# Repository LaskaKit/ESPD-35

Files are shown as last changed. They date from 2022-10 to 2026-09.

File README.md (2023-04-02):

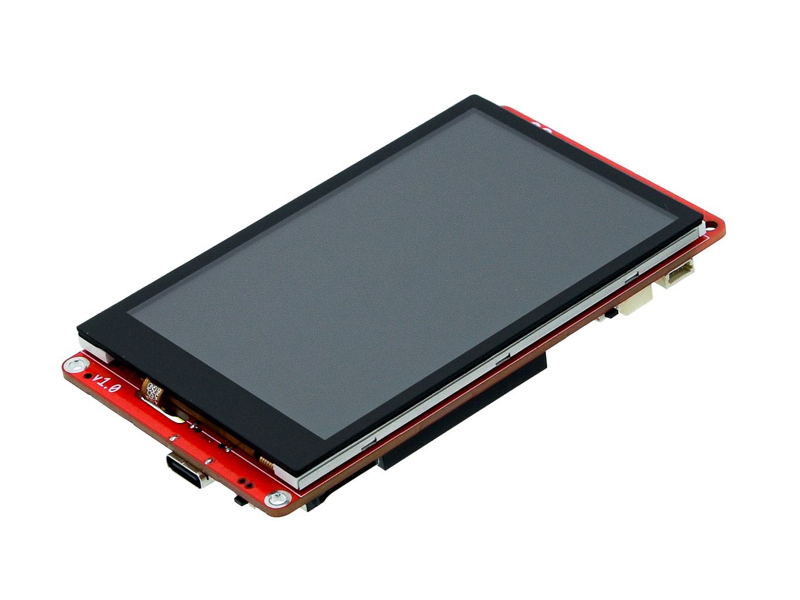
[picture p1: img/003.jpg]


# ESPD 3.5" - Development board with ESP32 and great TFT display

Don't you need a low-power board, but appreciate an active TFT display with a great viewing angle and quick connection of additional sensors and modules? What about ESPD-3.5"? Although it is a development kit, it is also suitable for fitting into the final product. The board has 4 mounting holes.

The 3.5" display has a resolution of 480x320 px and the number of colors of individual pixels can be up to 65535, and it also has a touch and includes a microSD card slot where you can store a lot of pictures and icons - instructions on how to do [this can be found here](https://blog.laskakit.cz/jak-nahrat-fotku-ikonu-do-esp32-a-zobrazit-na-tft-displeji/).

In addition to the SD card slot, the board has a module with ESP32 supporting Wi-Fi and Bluetooth connectivity, a built-in programmer with CH9102, a charging circuit for a battery with a charging current of 400mA, 2x uŠup connector for connecting sensors (for example [SHT40 ](https://www.laskakit.cz/laskakit-sht40-senzor-teploty-a-vlhkosti-vzduchu/)- temperature/humidity, [SCD41 ](https://www.laskakit.cz/laskakit-scd41-senzor-co2--teploty-a-vlhkosti-vzduchu/)- CO2/temperature/humidity or [BME280](https://www.laskakit.cz/arduino-senzor-tlaku--teploty-a-vlhkosti-bme280/) - pressure/temperature/humidity).

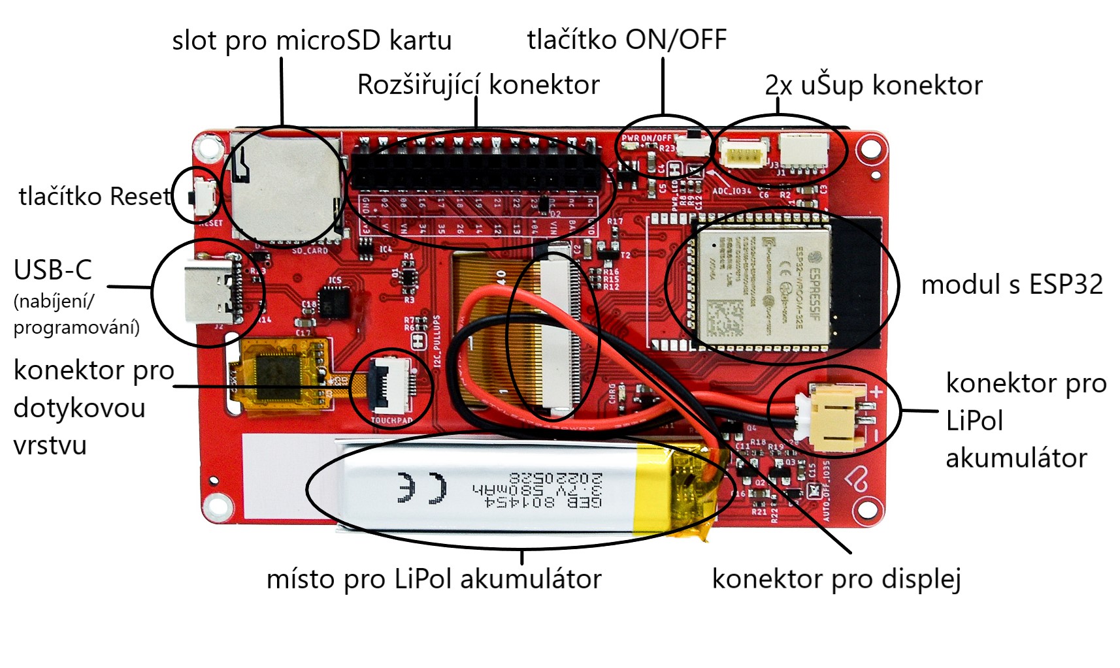
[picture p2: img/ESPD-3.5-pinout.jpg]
ESPD-3.5 pinout


The ESPD3.5" contains two buttons - RESET and Power ON/OFF - the button that turns the ESPD3.5" off (long press) and on (short press). The button is connected to GPIO35. You might also appreciate the 2x13 pin cavity rail where we connected the remaining ESP32 GPIO.

The USB-C connector is used for both programming and charging the Lipolka. We also left a [place on the board for a 580mAh Lipol battery](https://www.laskakit.cz/geb-lipol-baterie-801454-580mah-3-7v-jst-ph-2-0/) - so it won't get in the way anywhere else.

To measure the battery voltage, we also fitted a voltage divider connected to the battery and GPIO34 - don't forget to power the solder bridge.

**You can buy ESPD35 on https://www.laskakit.cz/laskakit-espd-35-esp32-3-5-tft-ili9488-touch/**

We have prepared some sample codes: https://github.com/LaskaKit/ESPD-35/tree/main/SW 

And also a box to print on a 3D printer: https://github.com/LaskaKit/ESPD-35/tree/main/3D

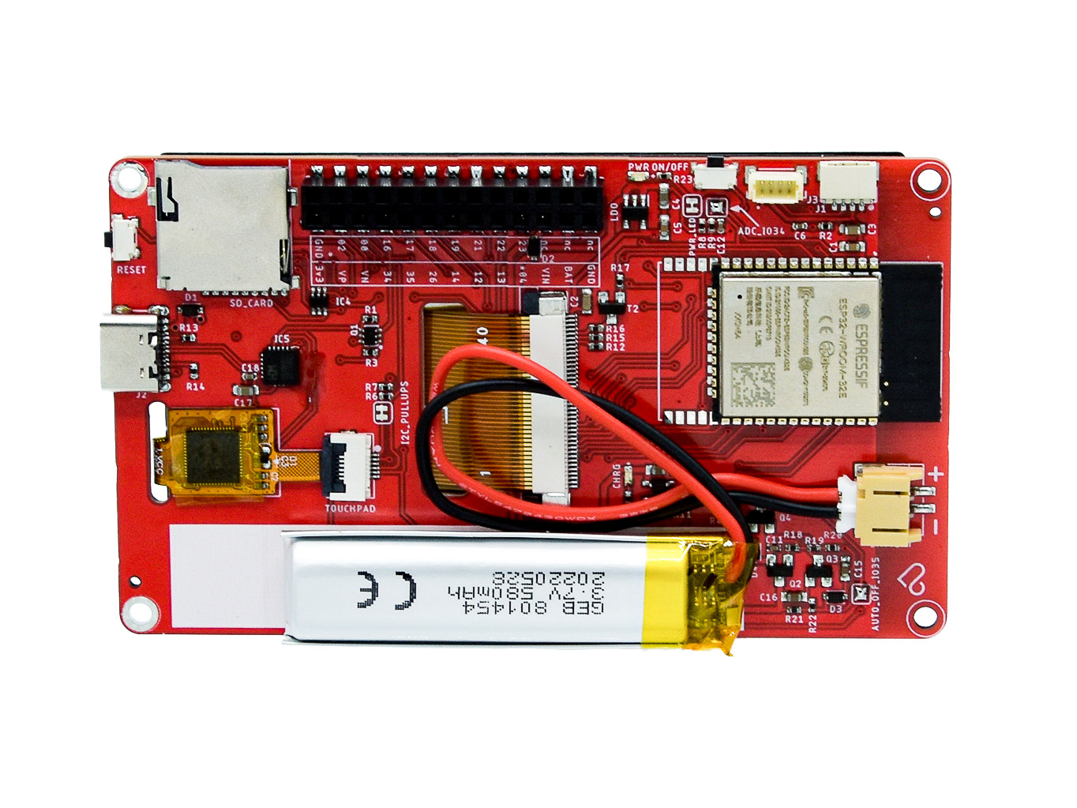
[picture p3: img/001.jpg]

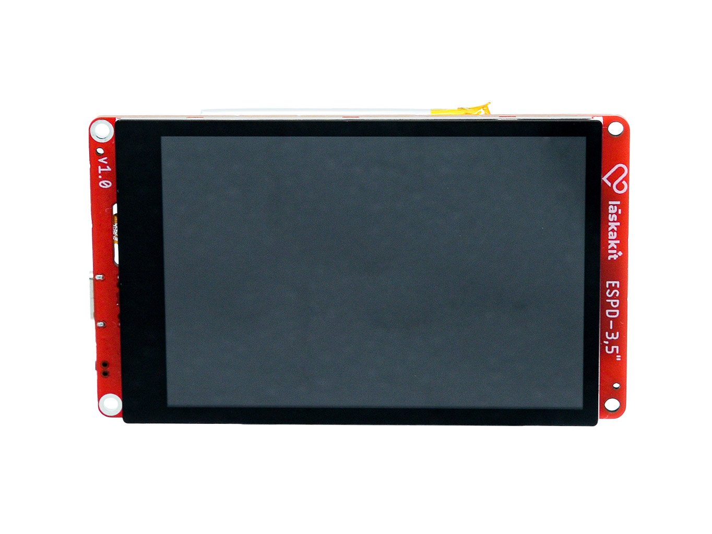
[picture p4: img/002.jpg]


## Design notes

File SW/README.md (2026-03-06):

# How to make display work

1. Download [CH343SER.EXE](http://www.wch-ic.com/search?t=all&q=CH9102) and install it.

2. Connect display to your PC and turn it on with button on the side of the device (**single press to turn on, long press to turn off**).

3. Open Device Manager (Start → Control Panel → Hardware and Sound → Device Manager) and find COM port number.

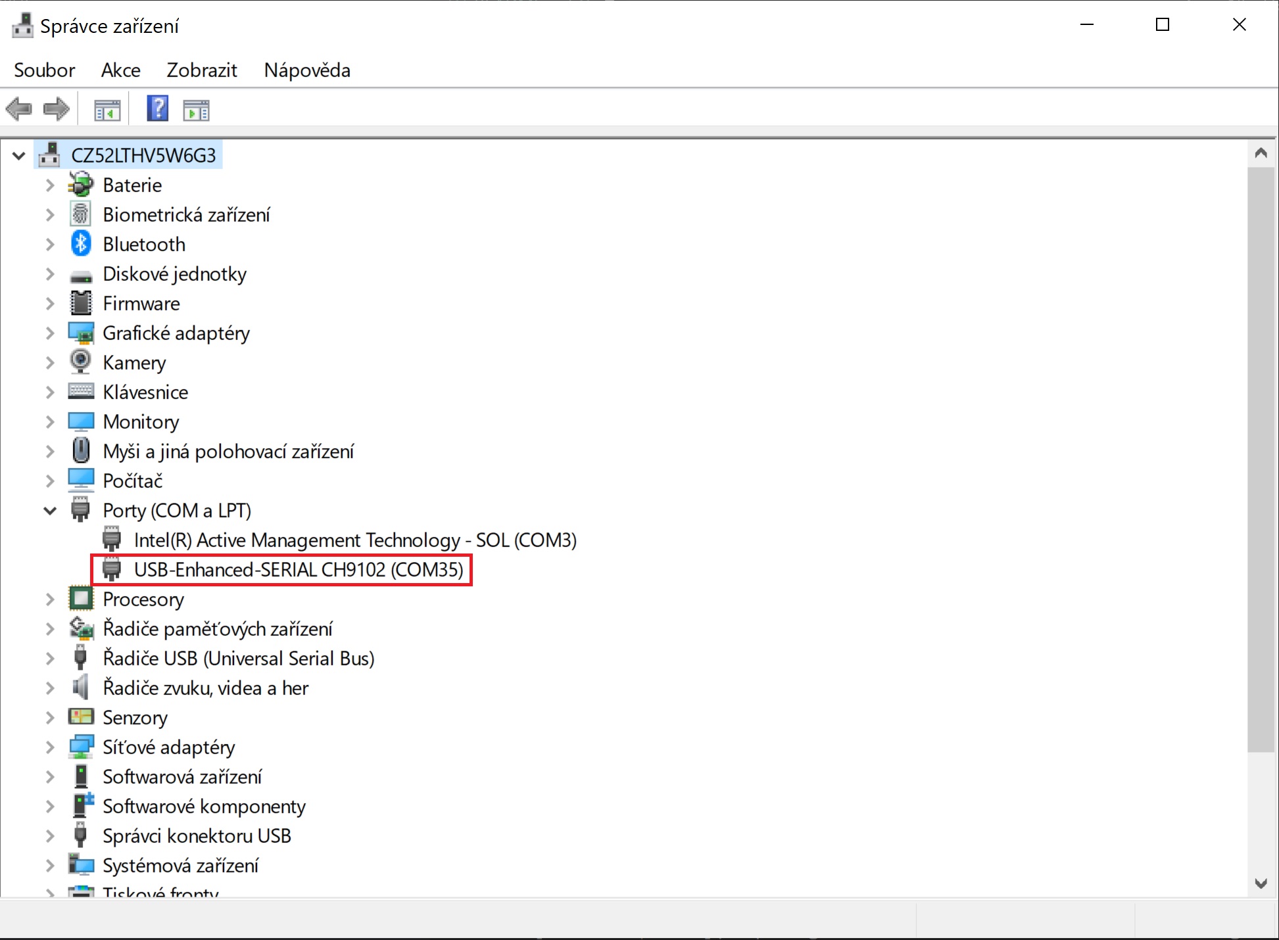
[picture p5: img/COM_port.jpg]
COM_port
    

## Arduino IDE
1. Download Github repository and look for project you want to try in [SW](../SW) folder.
2. Open example with Arduino IDE and set appropriate COM port and board type.
   
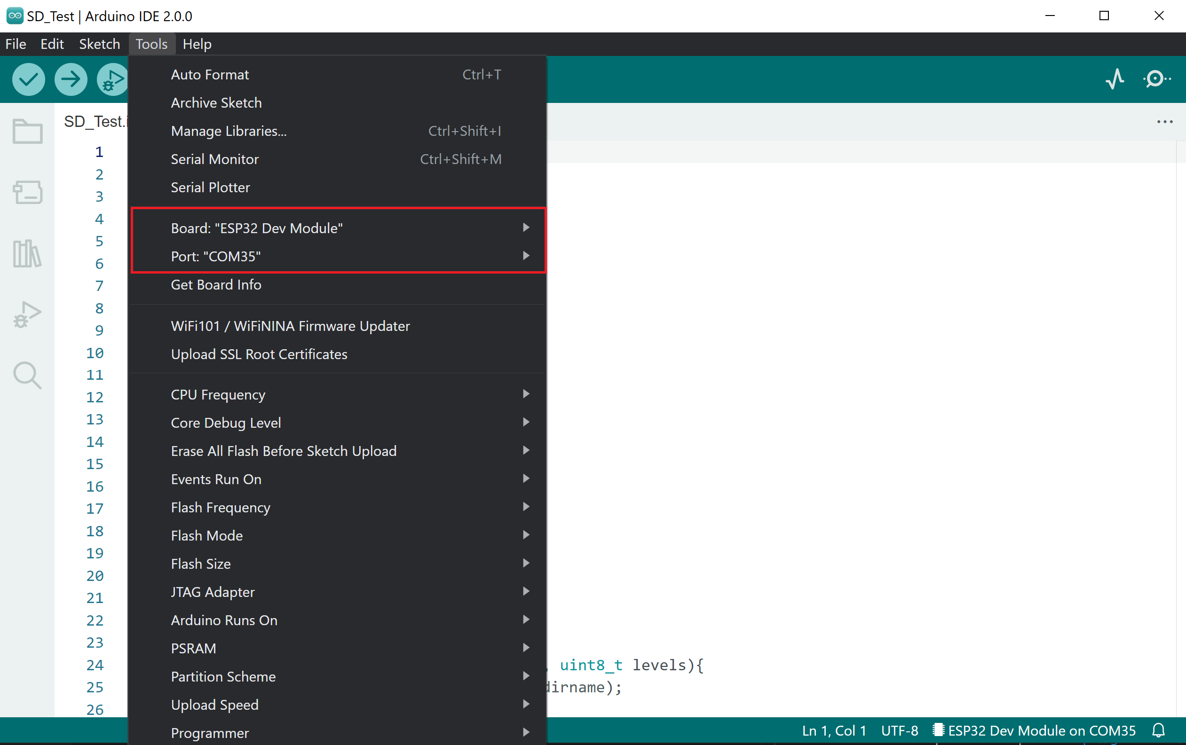
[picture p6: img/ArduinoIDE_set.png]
ArduinoIDE_set
    

3. Download necessary libraries.
4. You always need to adjust TFT_eSPI library to specific display. We  already prepared configuration file for this display ([Setup300_ILI9488_ESPD-3_5_v2.h](Setup300_ILI9488_ESPD-3_5_v2.h)) or for version v3 and above ([Setup300_ILI9488_ESPD-3_5_v3.h](https://github.com/LaskaKit/ESPD-35/blob/main/SW/Setup303_ILI9488_ESPD-3_5_v3.h)).
To use it, you need to copy this file to folder with your libraries: Arduino\libraries\TFT_eSPI\User_Setups.
1. In file Arduino\libraries\TFT_eSPI\User_Setup_Select.h you need to add this line: `#include <User_Setups/Setup300_ILI9488_ESPD-3_5_v2.h>` or for version v3 and above `#include <User_Setups/Setup300_ILI9488_ESPD-3_5_v3.h>`. into this section: `#ifndef USER_SETUP_LOADED` and comment `#include <User_Setup.h>` as shown in the picture and save it.
   
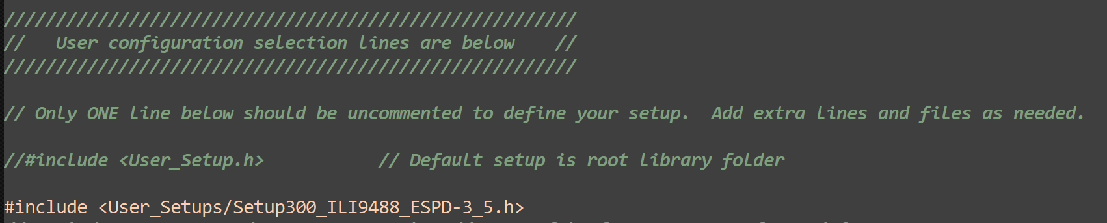
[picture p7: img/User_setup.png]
User_setup
   

2. Define version of hardware in code, for examples with touch functionality.
3. Upload the code.
## Platform IO
1. Download Github repository and look for project you want to try in [SW](https://github.com/LaskaKit/ESPD-35/tree/main/SW) folder.
2. Open example with Platform IO. COM port should be set automaticaly.
3. Libraries will be downloaded automatically, because of lib_deps in platformio.ini.
4. You always need to adjust TFT_eSPI library to specific display. For Platform IO, we can use build flags, so no file editing is necessary. Everything is already set in platformio.ini of every example.
    <p align="center">
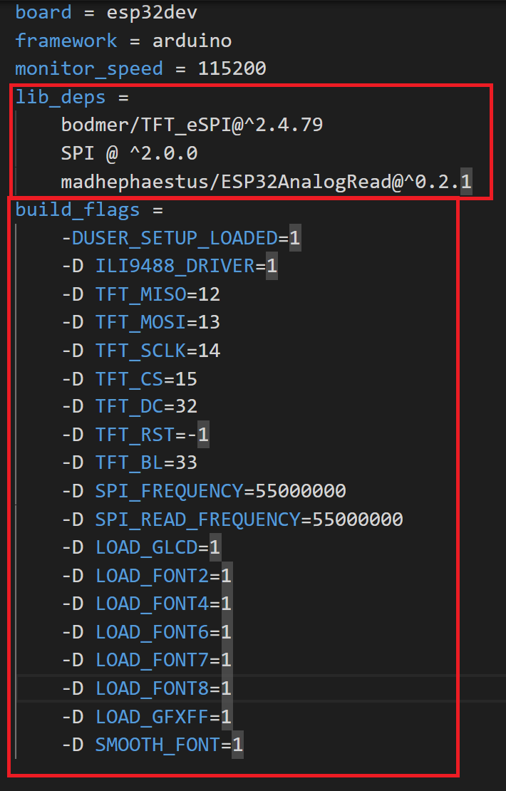
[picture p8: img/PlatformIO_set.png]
    
    </p>
5. Define version of hardware in code, for examples with touch functionality.
6. Upload the code.

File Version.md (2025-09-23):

### Version 3.2
- uSup connectors moved outside by 100 mil
- Switch moved far from connectors
- SHT40 moved.
#### Version 3.1
- Power button replaced with switch
#### Version 3.0
- New µc ESP32-S3-N16R8
- IPS Display
- New side GPIO connector
- added Temperature and Humidity SHT40 sensor
- (optional) added Inertial Measurement Unit BMI270
- (optional) I2S DAC and amplifier MAX98357A
#### Version 2.3
- Auto ON jumper added
#### Version 2.0
- SD card change to VSPI | Změna SD karty na VSPI
- HSPI only for display | HSPI pouze pro displej
- Změna pinu AUTO_OFF na GPIO17
#### Version 1.0
- Initial | Počáteční

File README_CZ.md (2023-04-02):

ESPD-3.5

# ESPD 3.5" - Vývojová deska s ESP32 a skvělým TFT displejem

Nepotřebuješ low-power desku, ale oceníš aktivní TFT displej se skvělým pozorovaním úhlem a rychlým připojením dalších čidel a modulů? ESPD-3.5". 
I když je to vývojový kit, je zároveň vhodný pro osazení do finálního produktu. Deska má 4 montážní díry. 

3.5" displej má rozlišení 480x320 px a počet barev jednotlivých pixelů může být až 65535 a navíc má i dotekovou 
ESPD-3.5" obsahuje slot na microSD kartu, kam si můžeš uložit spoustu obrázků a ikon - návod jak na to [najdeš tady](https://blog.laskakit.cz/jak-nahrat-fotku-ikonu-do-esp32-a-zobrazit-na-tft-displeji/).

Kromě slotu na SD kartu má deska samozřejmě modul s ESP32 podporující Wi-Fi i Bluetooth konektivitu, vestavěný programátor s CH9102, nabíjecí obvod pro akumulátor s nabíjecím
proudem 400mA, 2x konektor uŠup pro připojení čidel (například [SHT40](https://www.laskakit.cz/laskakit-sht40-senzor-teploty-a-vlhkosti-vzduchu/) - teplota/vlhkost, 
[SCD41](https://www.laskakit.cz/laskakit-scd41-senzor-co2--teploty-a-vlhkosti-vzduchu/) - CO2/teplota/vlhkost nebo [BME280](https://www.laskakit.cz/arduino-senzor-tlaku--teploty-a-vlhkosti-bme280/) - tlak/teplota/vlhkost).

ESPD-3.5 pinout

ESPD3.5" obsahuje dvě tlačítka - RESET a Power ON/OFF - tlačítko, kterým ESPD3.5" vypneš (dlouhý stisk) a zapneš (krátký stisk). Tlačítko je připojeno k GPIO35.
Ocenit bys mohl i dutinkovou lištu 2x13 pinů, kam jsme připojili zbylé GPIO ESP32.

USB-C konektor slouží jak k programování, tak i nabíjení Lipolky. 
Na desce jsme nechali i místo pro [580mAh Lipol akumulátor](https://www.laskakit.cz/geb-lipol-baterie-801454-580mah-3-7v-jst-ph-2-0/) - aby nikde jinde nepřekážel. 

K měření napětí akumulátoru jsme osadili i napěťový dělič připojený k akumulátoru a GPIO34 - nezapomeň propájet pájecí most. 

**Deska je dostupná na https://www.laskakit.cz/laskakit-espd-35-esp32-3-5-tft-ili9488-touch/**

Připravili jsme několik vzorových kódů: https://github.com/LaskaKit/ESPD-35/tree/main/SW

A také krabičku k vytištěnní na 3D tiskárně: https://github.com/LaskaKit/ESPD-35/tree/main/3D

ESPD-3.5
ESPD-3.5

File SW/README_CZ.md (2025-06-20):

# Jak pracovat s displejem

1. Stáhnout [CH343SER.EXE](http://www.wch-ic.com/search?t=all&q=CH9102) a nainstalovat. Návod i na našem [blogu](https://blog.laskakit.cz/instalace-ovladace-prevodniku-usb-na-uart-ch340/).

2. Zapojit displej do PC a zapnout tlačítkem na boku (**stisk pro zapnutí, dlouhý stisk pro vypnutí**).

3. Start – Systém – Správce zařízení (může být potřeba oprávnění správce) najít položku Porty (COM a LPT).

    COM_port

## Arduino IDE
1. Stáhnout Github repository a otevřít příklad, který chcete zkusit ze složky [SW](../SW).
2. Otevřít příklad pomocí Arduino IDE a nastavit správný COM port a typ desky.
   
    ArduinoIDE_set

3. Stáhnout nezbytné knihovny.
4. Knihovnu TFE_eSPI je vždy potřeba nastavit podle konkrétního displeje. Pro tento displej je už konfigurační soubor připravený ([Setup300_ILI9488_ESPD-3_5_v2.h](Setup300_ILI9488_ESPD-3_5_v2.h)) nebo pro verze v3 ([Setup300_ILI9488_ESPD-3_5_v3.h](Setup300_ILI9488_ESPD-3_5_v3.h)).
Musí být pouze zkopírován do složky knihovny: Arduino\libraries\TFT_eSPI\User_Setups.
5. V souboru Arduino\libraries\TFT_eSPI\User_Setup_Select.h je poté potřeba přidat řádek: `#include <User_Setups/Setup300_ILI9488_ESPD-3_5.h>` nebo pro verze v3 `#include <User_Setups/Setup300_ILI9488_ESPD-3_5_v3.h>` do sekce: `#ifndef USER_SETUP_LOADED` a zakomentovat `#include <User_Setup.h>`, jak je znázorněno v obrázku níže.
   
   User_setup

6. Definovat verzi hardware v kódu pro příklady s funkcí dotyku.
7. Nahrát kód.
## Platform IO
1. Stáhnout Github repository a otevřít příklad, který chcete zkusit ze složky [SW](../SW).
2. Otevřít příklad pomocí Arduino IDE a nastavit správný COM port a typ desky. COM port by měl být nastaven automaticky.
3. Knihovny se stáhnou automaticky díky lib_deps v souboru platformio.ini.
4. Knihovnu TFE_eSPI je vždy potřeba nastavit podle konkrétního displeje. V Platform IO můžeme opět použít build flags, takže není potřeba upravovat žádné soubory. Všechno je už nastaveno v platformio.ini v každém příkladu.
    <p align="center">
    
    </p>
5. Definovat verzi hardware v kódu pro příklady s funkcí dotyku.
6. Nahrát kód.

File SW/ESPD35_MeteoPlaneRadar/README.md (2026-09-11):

# ESPD35 MeteoPlaneRadar

Hodiny, radar letadel, srážkový meteoradar a předpověď počasí na desce
**LaskaKit ESPD‑3.5"**. Bez pájení — stačí deska, USB‑C kabel a WiFi.

> Vychází z [petus/MeteoPlaneRadar](https://github.com/petus/MeteoPlaneRadar)
> (autor Petr, původně pro chiptron.cz). Portováno a rozšířeno pro
> [laskakit.cz](https://www.laskakit.cz).

---

## Co to umí

Pět obrazovek. Přepínají se dlouhým stiskem nebo klepnutím na tečky dole.
Čtyři z nich se dají vypnout.

| Obrazovka | Co ukazuje |
| --- | --- |
| 🕐 **Hodiny** | Čas, datum, aktuální počasí, vítr, východ a západ slunce. Sekundy běží po elipse kolem displeje. |
| ✈️ **Letadla** | Radar z [adsb.fi](https://adsb.fi) — silueta natočená podle kurzu, barva podle letové hladiny. V panelu detail nejbližšího letadla včetně trasy letu. Rozsahy 10 / 25 / 50 / 100 km. |
| 🌧️ **Meteoradar** | Srážky z [ČHMÚ](https://opendata.chmi.cz), animace 6 snímků za posledních 25 minut. Rozsahy 25 / 50 / 100 / 200 km a celá ČR. |
| 🌤️ **Předpověď** | 6 hodin, 3 dny, ovzduší (AQI, PM2.5, pyl). Z [Open‑Meteo](https://open-meteo.com). |
| ⚙️ **Nastavení** | Jas, orientace mapy, jednotky, adresa webu, tovární reset. |

Všechno ostatní se nastavuje **v prohlížeči** — poloha, obrazovky, filtry
letadel, WiFi i aktualizace firmwaru.

Polohu není třeba zadávat, zjistí se podle IP adresy.

---

## Hardware

| | |
| --- | --- |
| Deska | [LaskaKit ESPD‑3.5" ESP32‑S3 TFT ILI9488 CAP Touch Rev. 3.2](https://www.laskakit.cz/laskakit-espd-35-esp32-3-5-tft-ili9488-touch/?variantId=12161) |
| Displej | 3.5" TFT ILI9488, 480×320, SPI |
| Dotyk | kapacitní FT5436 (I2C) |
| Krabička | [Krabička pro ESPD‑3.5"](https://www.laskakit.cz/laskakit--krabicka-pro-espd-35/?variantId=12574) |

Deska nemá žádné tlačítko — ovládá se celá dotykem.

---

# Pro uživatele: nahrání bez programování

Nepotřebuješ Arduino IDE ani nic instalovat. Stačí prohlížeč.

**Potřebuješ:** Chrome nebo Edge (Firefox a Safari to neumí) a USB‑C kabel,
který vede i data — ne jen nabíjecí.

1. Otevři **webový flasher** (odkaz na stránce projektu).
2. Připoj desku do počítače kabelem ke konektoru označenému **„USB"**.
3. Klikni na **Connect** a v seznamu vyber port desky.
4. Klikni na **Install** a počkej. Deska se sama restartuje.

### První spuštění

1. Deska vytvoří otevřenou WiFi síť **`ESPD35-MeteoPlaneRadar`**.
2. Na displeji se ukáže **QR kód** — naskenuj ho telefonem a připoj se.
3. V prohlížeči otevři **`http://192.168.4.1/`**, vyber svou WiFi a zadej heslo.

Deska čeká, dokud síť nezadáš — žádný časový limit. Telefon nahlásí, že síť
nemá internet; to nevadí.

Potom najdeš nastavení na **`http://espd35meteoradar.local/`** (adresa je
i na obrazovce Nastavení).

### Ovládání dotykem

| Gesto | Co udělá |
| --- | --- |
| Dlouhý stisk vlevo / vpravo | předchozí / následující obrazovka |
| Klepnutí na tečky dole | skok na danou obrazovku |
| Přejetí prstem vlevo / vpravo | změna rozsahu |
| Klepnutí na letadlo | zafixuje ho v detailu |
| Klepnutí do prázdné mapy | zpět na nejbližší letadlo |

### Nastavení v prohlížeči

Šest záložek:

- **Stav** — čas, adresa, signál, doba běhu, volná paměť, stav zdrojů dat.
  Odsud jde přepnout obrazovku i rozsah na dálku.
- **Poloha a displej** — poloha (ručně nebo vyhledáním města), jas ve dne
  a v noci, automatické přepínání podle slunce.
- **Obrazovky** — které se zobrazují, automatické střídání, styl sekund.
- **Letadla** — jednotky, orientace mapy, výškové pásmo, filtry, hlídaný znak.
- **WiFi** — vyhledání sítí a připojení.
- **Správa** — heslo, záloha nastavení, aktualizace firmwaru, tovární reset.

Změny platí **po klepnutí na Uložit nastavení**. Restart není potřeba.

### Orientace mapy

V Nastavení se volí, **který světový směr je nahoře** na radaru letadel — tedy
směr, kterým se díváš z okna. Nastavíš `V` a letadla na displeji jsou ve stejném
směru jako ta za sklem. Meteoradar se záměrně neotáčí, srážky se čtou severem
nahoru.

### Aktualizace firmwaru

Ve **Správě** vyber soubor `ESPD35_MeteoPlaneRadar.ino.bin` (ten **bez**
„merged") a klikni na Nahrát. Průběh je vidět v prohlížeči i na displeji.
Když se to nepovede, zůstane v desce původní verze.

### Když se něco pokazí

| Problém | Řešení |
| --- | --- |
| Displej je černý | Nahrávalo se se špatným nastavením PSRAM. Nahraj znovu přes webový flasher. |
| Prázdný meteoradar | Když neprší, kompozit je skoro černý. To je normální. |
| Prázdný radar letadel | Zkus větší rozsah. V noci nebo mimo koridory nemusí být nic. |
| Deska se nepřipojí k WiFi | Síť sama zapomene a vrátí se k QR kódu. Zkus zadat heslo znovu. |
| Nejde `espd35meteoradar.local` | Použij IP adresu z obrazovky Nastavení. |
| Zapomenuté heslo správce | Tovární reset na obrazovce Nastavení (dvě klepnutí na červené tlačítko). |

---

# Pro vývojáře: překlad ze zdrojáků

### Knihovny

V Arduino IDE (**Nástroje → Spravovat knihovny**):

| Knihovna | Autor |
| --- | --- |
| GFX Library for Arduino | moononournation (**ne** Adafruit GFX) |
| PNGdec | bitbank2 |
| ArduinoJson (v7) | bblanchon |
| FT6236 | DustinWatts — přikládá LaskaKit k desce |

QRCode (ricmoo) je přibalený v projektu. Zbytek je součást ESP32 core:
`WebServer`, `DNSServer`, `ESPmDNS`, `Update`, `Preferences`, `HTTPClient`.

> WiFiManager ani ElegantOTA se od 0.4.0 **nepoužívají**. Portál i nahrávání
> firmwaru obsluhuje vlastní web server. ElegantOTA je pod AGPL‑3.0, což
> u zařízení obsluhujícího webovou stránku není zadarmo.

### Nastavení Arduino IDE

**Nástroje →**

| Položka | Hodnota |
| --- | --- |
| Deska | ESP32S3 Dev Module |
| **PSRAM** | **OPI PSRAM** ← bez toho zůstane displej černý |
| Flash Size | 16MB (128Mb) |
| **Partition Scheme** | **Custom** ← použije přiložený `partitions.csv` |
| USB CDC On Boot | Disable |
| Upload Speed | 921600 |

Partition **Custom** je nutná pro OTA — tabulka má dvě aplikační oblasti
po 6 MB. Po překladu zkontroluj v logu `of 6291456 bytes`.

Alternativně `arduino-cli compile --profile default` — verze core i knihoven
jsou připnuté v `sketch.yaml`.

### Piny (Config.h)

Předvyplněné pro ESPD‑3.5 Rev 3.2:

```c
#define TFT_SCK   12      // displej ILI9488 (SPI)
#define TFT_MOSI  11
#define TFT_MISO  13
#define TFT_CS    48
#define TFT_DC    47
#define TFT_RST   -1
#define TFT_BL    45
#define I2C_SDA   42      // dotyk FT5436
#define I2C_SCL    2
```

### Struktura

| Soubor | K čemu |
| --- | --- |
| `Config.h` | **jediný soubor, který obvykle měníš** — piny, časová zóna, rozsahy, intervaly, limity |
| `Version.h` | verze firmwaru |
| `Settings.*` | nastavení v NVS + serializace do JSON |
| `Net.*` | HTTPS GET na jednom místě, kontrola paměti |
| `Status.*` | stav zdrojů dat pro webovou stránku |
| `Layout.*` | pevné pásy obrazovek + kontrola překryvů |
| `Lang.*` | texty (ASCII na displej, UTF‑8 na web) |
| `ADSB.*`, `Route.*` | letadla a trasy letů |
| `CHMU.*` | srážkový kompozit |
| `Forecast.*` | předpověď, slunce, ovzduší — jedním požadavkem |
| `EuBorder.*`, `EuMapData.h` | hranice a města |
| `Screen*.cpp` | jednotlivé obrazovky |
| `WebConfig.*`, `WebPage.h` | web server a stránka |
| `WiFiPortal.*` | připojení a přístupový bod |

### Na co si dát pozor

- **Krátké názvy velkými písmeny.** `xtensa/config/specreg.h` obsazuje `MR`,
  `BR`, `PS`, `SAR`, `DDR`, `EPC`, `MISC`, `M0`–`M3` a další. Používej popisné
  názvy.
- **Názvy hlaviček** nesmí kolidovat se systémovými ani při ignorování velikosti
  písmen — proto `Lang.h`, ne `Strings.h`.
- **Z obsluhy HTTP požadavku se nikdy nekreslí.** Požadavky se řadí do fronty
  a provádí je `loop()`. Jediná výjimka je průběh OTA.
- **Font je 7bitové ASCII.** Na displej patří text bez diakritiky — `Lang.h`
  drží obě verze.
- **Klíče v NVS se nepřejmenovávají**, aby desky po aktualizaci nepřišly
  o nastavení. Když se mění význam, zakládá se nový klíč.
- **Layout: jedna skupina = jeden nárok.** Hodnota a jednotka se nesmí
  narokovat zvlášť, obdélníky by se překryly a druhý nárok Layout odmítne.

### Sériový výstup (115200 Bd)

Přes konektor označený **„USB"** (nativní USB ESP32‑S3), ne přes ten druhý.

```
=== ESPD35_MeteoPlaneRadar v0.4.0 ===
Duvod restartu: zapnuti napajeni
WiFi ok, IP 192.168.1.42
Web: http://espd35meteoradar.local/
Letadla: 11 (8421 bajtu)
Meteoradar: 6 ramcu
Predpoved: 6 h / 3 d
```

Podrobnější výpisy: `TOUCH_DEBUG` a `LAYOUT_DEBUG` v `Config.h`.

---

## Zdroje dat

| Data | Zdroj | Poznámka |
| --- | --- | --- |
| Letadla, registrace a typ | [adsb.fi](https://adsb.fi/) | zdarma, bez klíče |
| Trasy letů | [adsb.lol](https://adsb.lol/) | zdarma, bez klíče; ověřuje trasu proti poloze letadla |
| Srážky | [ČHMÚ OpenData](https://opendata.chmi.cz/) | kompozit MAX_Z, nový snímek ~5 min |
| Počasí | [Open‑Meteo](https://open-meteo.com/) | zdarma, bez klíče |
| Poloha | [ip‑api.com](https://ip-api.com/) | detekce podle IP |
| Mapa | Natural Earth, GeoNames | volné dílo / CC BY 4.0 |

> ⚠️ Zdroje vyžadují uvedení. Bezplatná API jsou pro **osobní nekomerční
> použití**; pro komerční nasazení si zajisti odpovídající přístup k datům.

---

## Licence

Kód je pod **MIT**. Vložená knihovna QRCode (ricmoo) rovněž MIT.
Data ČHMÚ, adsb.fi, adsb.lol a Open‑Meteo podléhají podmínkám poskytovatelů.

Historie změn: [CHANGELOG.md](CHANGELOG.md).

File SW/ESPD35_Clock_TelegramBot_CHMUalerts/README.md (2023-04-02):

# Článek je dostupný na https://chiptron.cz/articles.php?article_id=325
English version https://chiptron-cz.translate.goog/articles.php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

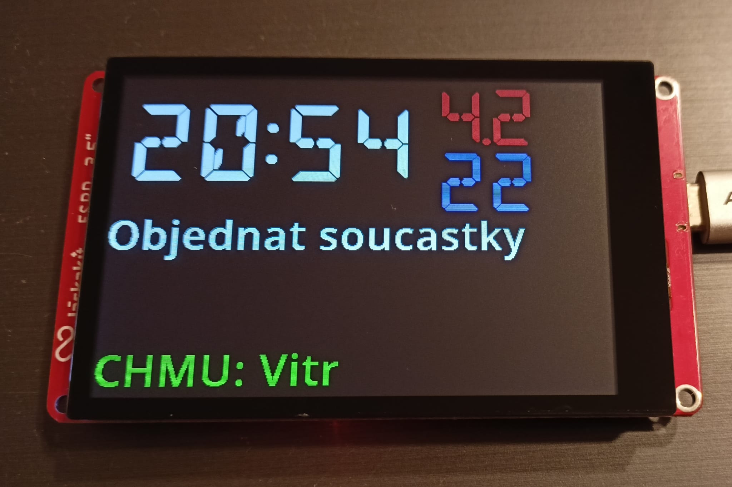
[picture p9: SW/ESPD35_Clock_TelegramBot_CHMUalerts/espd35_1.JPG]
Clock, temperature, humidity, Telegram, Alerts


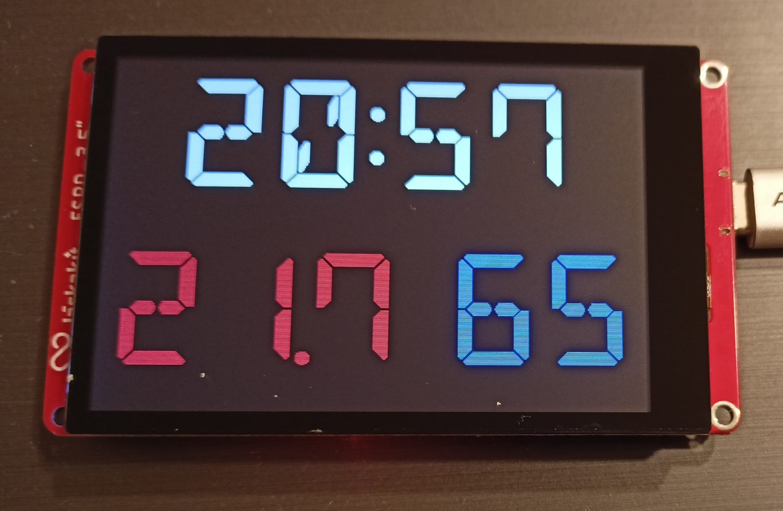
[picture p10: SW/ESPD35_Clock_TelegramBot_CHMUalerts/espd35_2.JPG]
No telegram and Alerts


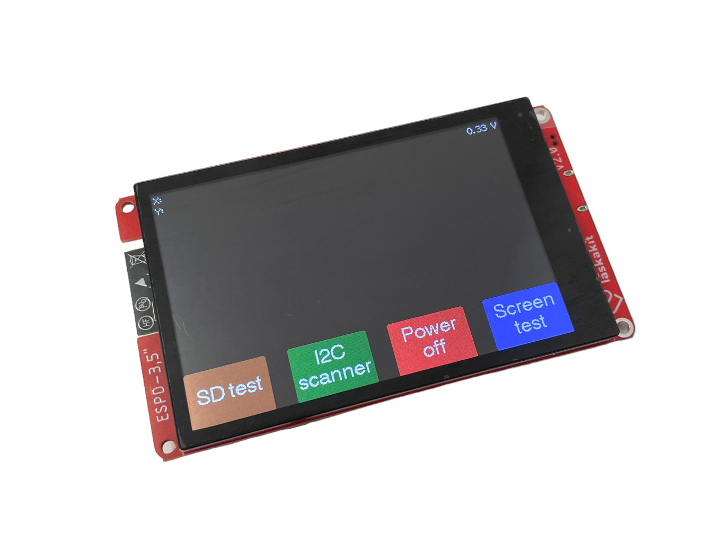
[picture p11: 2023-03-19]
img/example.jpg

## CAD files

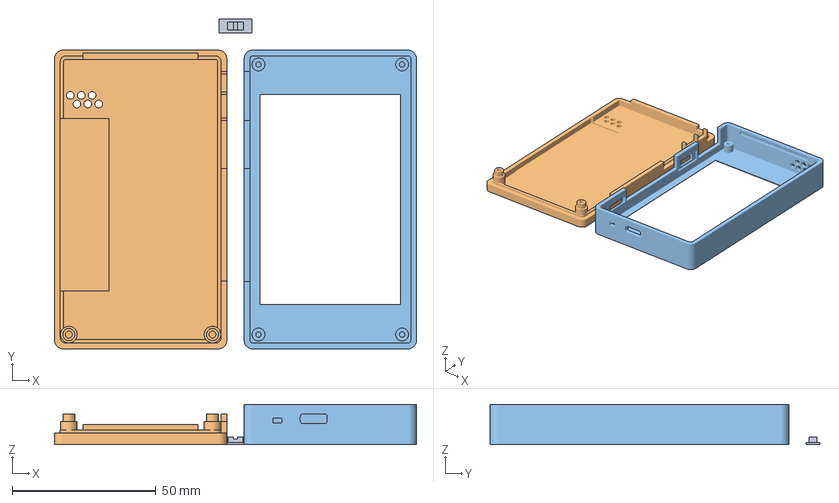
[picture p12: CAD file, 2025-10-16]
3D/ESPD-35_case_v3.3mf
126.0 x 114.8 x 14.0 mm
switch v3
Bottom_cover_v3 v11
Top_cover v28

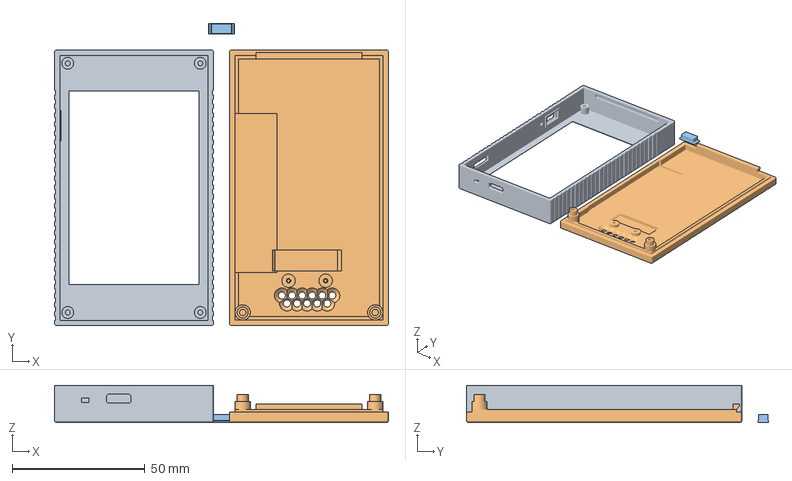
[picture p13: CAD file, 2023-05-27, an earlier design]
3D/old/ESPD-35_case.3mf
126.0 x 114.1 x 14.0 mm
Top_cover v64.stl
Bottom_cover_general v37.stl
button v5.stl

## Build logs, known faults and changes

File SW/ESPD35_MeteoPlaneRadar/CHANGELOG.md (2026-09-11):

# Changelog

Změny v projektu **ESPD35_MeteoPlaneRadar**.
Verze je na jediném místě: `Version.h` (`FW_VERSION`).

---

## [0.4.2]

### Opraveno

- **Trasa letu se nezobrazovala.** `deserializeJson()` četl přímo
  z `http.getStream()`, což je surový socket: když adsb.lol odpoví chunked,
  jdou hexadecimální hlavičky bloků rovnou do parseru a ten vrátí `Ok` nad
  prázdným dokumentem.
- **Radar letadel mohl zůstat prázdný** ze stejné příčiny — hlavičky bloků
  zůstávaly v těle a pole `ac` v dokumentu chybělo. Těla se nově čtou přes
  `writeToStream()`, které chunked dekóduje.
- **Snímek meteoradaru se mohl vykreslit poškozený**, protože stahování PNG
  četlo socket stejným ručním způsobem.
- **Zařízení se mohlo restartovat během TLS handshake.** Ten má vlastní limit
  120 s, tedy šestinásobek watchdogu; nově 8 s.
- **Stažení trasy mohlo restartovat zařízení**, protože se během něj
  neresetoval watchdog. Přibylo `Route_SetPollFn()`.
- **Letadlo na zemi se počítalo jako v nulové výšce.** `alt_baro` u nich nese
  text `ground`, ze kterého `atof()` udělal 0.0 a ohlásil úspěch; nově
  `strtof()` s koncovým ukazatelem.

### Změněno

- Index ČHMÚ se prohledává za běhu v klouzavém okně, takže na jeho velikosti
  nezáleží. Odpadl i desetisekundový timeout, na který dobíhalo každé stažení.
- Sériový výpis říká velikost indexu ČHMÚ a u nečekané odpovědi z adsb.fi
  její `msg` a začátek těla.

---

## [0.4.1]

### Opraveno

- **V detailu letadla se ukazovala trasa, která neodpovídala skutečnosti** —
  třeba Atény → Istanbul u letadla nad Prahou. Sešly se tři příčiny:
  letadlo bez volací značky poslalo do dotazu svou ICAO adresu (`a31234` se
  normalizuje na `A31234`, což je platné číslo letu Aegean Airlines 1234),
  zdroj tras neověřoval polohu, a u letů s mezipřistáním se ukazoval první
  odlet a poslední přílet, i když letadlo letělo prostřední úsek.
- **Místo typu letounu se u některých letadel ukazovalo `adsb_icao`.** To je
  typ zprávy, ne typ draku; jako záloha se používat neměl. Když adsb.fi drak
  nezná, řádek se teď prostě nevykreslí.
- **Hlavička `User-Agent` se neposílala vůbec.** `HTTPClient::addHeader()` ji
  mlčky zahazuje, takže odcházelo výchozí `ESP32HTTPClient`.
- **Trasa se dokreslila až s dalším stažením letadel**, o několik sekund
  později, než dorazila. Nově se objeví hned.
- **Keš tras si odpověď pamatovala až do restartu.** Volací značky se recyklují
  a výsledek platí k poloze, se kterou se ptalo, takže po mezipřistání
  ukazoval pořád první úsek. Záznam teď platí 20 minut (1 minutu, když
  trasa nebyla nalezena).

### Změněno

- **Trasy nově z adsb.lol** místo adsbdb.com. Spolu s volací značkou se posílá
  i poloha letadla a server vrátí, jestli k ní trasa vůbec sedí — co neprojde,
  se nezobrazí. U letů s mezipřistáním se vybere ten úsek, který letadlo právě
  letí. Letadlo, které volací značku nevysílá, se na trasu neptá vůbec.
- **Registrace a typ letounu se berou z adsb.fi** (pole `r` a `t`) ze stejné
  odpovědi, která se stahuje kvůli polohám. Odpadl tím dotaz na druhé API
  a registrace se ukáže i u letadla bez trasy.

---

## [0.4.0]

Konfigurace se přesunula do prohlížeče, přibyly hodiny a předpověď.

> **Aktualizace z 0.3.0:** rozdělení paměti se nemění, jde přes OTA.
> Poslední zobrazená obrazovka se převede automaticky (nový klíč `scr2`).

### Přidáno

- **Obrazovka hodin** — čas, datum, počasí, vítr, východ a západ slunce.
  Ukazatel sekund běží po elipse; čtyři styly (vypnuto / tečky / čára /
  kometa), barvy se nastavují na webu. Klepnutí přepne den/noc, když je
  automatika vypnutá.
- **Obrazovka předpovědi** — 6 hodin, 3 dny, ovzduší (AQI, PM2.5, pyl).
- **Webová konfigurace** na `http://espd35meteoradar.local/`, v záložkách.
  Poloha (i vyhledáním města), jas, obrazovky, jednotky, orientace mapy,
  filtry letadel, WiFi, záloha a obnova, aktualizace firmwaru.
  Stránka je jeden soubor bez externích závislostí — funguje i z přístupového
  bodu, kde deska nemá internet.
- **Stav zdrojů dat** na webu: čas, adresa, signál, doba běhu, volná paměť
  a jednořádkové hlášení ADS‑B, meteoradaru a předpovědi. Plus přepínání
  obrazovek a rozsahu na dálku.
- **Automatický noční jas** podle východu a západu slunce, s posunem ±120 min.
- **Evropská mapa** (30 894 bodů hranic, 1 100 měst) místo obrysu ČR.
- **Pátý rozsah meteoradaru: celá ČR** — pevný výřez státu bez ohledu na polohu.
- **Trasa letu** v detailu letadla: odkud, kam, registrace.
- **Nouzový squawk** (7500/7600/7700) — červený pruh v detailu. Letadlo v nouzi
  se zobrazí i mimo nastavené výškové pásmo.
- **Pět obrazovek, čtyři vypínatelné**, plus automatické střídání.
  Vypnutá obrazovka nemá tečku a přeskočí ji dlouhý stisk i střídání.
- **Filtry letadel**: výškové pásmo, jen se znakem volání, hlídaný volací znak.
- **Heslo správce** — chrání aktualizaci firmwaru, obnovu ze zálohy a reset.

### Změněno

- **Pryč ElegantOTA.** Je pod AGPL‑3.0 a u zařízení s webovou stránkou se
  licence uplatní. Nahradila ho třída `Update` z ESP32 core, kterou ElegantOTA
  stejně jen obalovala — o jednu závislost míň.
- **Pryč WiFiManager.** Blokoval smyčku (kvůli tomu se musel uspávat watchdog)
  a jeho portál je anglický. Náhradou je vlastní přístupový bod a stránka
  projektu. **Přístupový bod nemá časový limit.**
- **Žádná změna nastavení nevyžaduje restart.** Restart zůstal jako tlačítko
  ve Správě a u obnovy ze zálohy.
- **`Net.*`** — jedno místo pro HTTPS. Kontroluje volnou interní paměť, protože
  TLS handshake potřebuje ~45 kB; bez toho selže jako nic neříkající `HTTP -1`.
- **Dotyk se neztrácí během stahování.** Snímání běží i uvnitř přenosu,
  provedení až v `loop()`.
- **Obrazovka Nastavení**: místo dvou tlačítek je tam „Znovu nastavit WiFi“
  a adresa webu.
- **`Watchdog_Suspend()` / `Resume()` zrušeny** — nic už smyčku neblokuje.

### Opraveno

- **Jednotky u předpovědi a hodnoty ovzduší se nekreslily.** Hodnota a jednotka
  si o místo říkaly zvlášť a druhý nárok Layout vždy odmítl, protože obdélníky
  se překrývaly. Skupina teď zabírá jeden obdélník.
- **Tlačítko „Uložit nastavení“ bylo jen v záložce Správa** — schovalo se
  s ní, takže změny z ostatních záložek nešlo uložit. Teď je pod všemi.
- **Východ a západ slunce nešly přečíst** (tmavá šedá, velikost 1) → světlá
  šedá, velikost 2.
- **Ikony počasí splývaly s pozadím**, nejvíc u deště a bouřky. Přibyla světlejší
  šedá pro mraky.
- **Běh sekund nebyl v krabičce vidět** — vedl po samém okraji. Teď je to
  elipsa s odsazením 16 px.
- **Ohon komety byl příliš krátký** (5 s) → 20 s, plynulé hasnutí.
- **Detail letadla zůstával na stroji mimo mapu** → vrátí se na nejbližší,
  jakmile je vybrané letadlo dál než zobrazený rozsah.
- **Detail letadla byl celý drobný** → hodnota velikosti 2, popisek a jednotka
  malé. Když se to nevejde, hodnota se zmenší, místo aby přetekla.
- **Modrý obdélník u předpovědi na dny** (sloupeček srážek bez měřítka) zrušen.
- **Druh pylu byl na místě jednotky** → je v popisku (`Pyl travy`), číslo velké.
  Jednotka se u pylu neuvádí: bez tabulky prahů stejně nic neřekne.
- **PM2.5 mělo jednotku `ug`** — nedokončenou. Správně `ug/m3`.
- **Srážky u předpovědi na hodiny se nekreslily.** Řádek zabírá 20 px, ale
  oddělovací čára pod hodinovým pásem stála 16 px pod ním, takže nárok
  kolidoval a Layout ho odmítl. Svislé rozestupy jsou přepočítané a hlídá
  je test, který konstanty čte přímo ze zdrojáku.
- **Automatické střídání obrazovek se nerozjelo.** Dvě příčiny:
  z obrazovky Nastavení se záměrně nikdy neodcházelo, takže deska nechaná
  na Nastavení se sama nevrátila k datům; a pauza po doteku byla pevných
  10 minut bez ohledu na interval — po jediném doteku se u desetisekundového
  střídání deset minut nedělo nic. Nově se z Nastavení odchází taky (uživatele
  chrání pauza) a pauza je desetinásobek intervalu, nejméně 30 s a nejvýše
  10 minut. Nově uložená hodnota navíc platí okamžitě, nečeká se na doběhnutí
  staré pauzy. V záložce Stav je vidět, jestli je střídání vypnuté, nebo jen
  pozastavené a na jak dlouho.
- **Teploty měly barvu podle počasí, ne podle teploty** — 18 °C mohlo být
  červené a 22 °C modré. Barva teď znamená teplotu (modrá → červená),
  stav počasí nese ikona nad číslem. Platí i pro denní maxima a minima.
- **Posuvník jasu neříkal, kterou úroveň nastavuje** → `Jas (den, automaticky)`.
- **Vítr byl schovaný pod teplotou** → pod hodinami, velikost 2.
- **Tečky obrazovek byly moc velké** (poloměr 6 → 4).
- **Podpis „laskakit.cz“ zabíral místo v panelu letadel** → odstraněn.
- **Nešlo přeložit na Windows.** `Strings.h` kolidoval se systémovým
  `<strings.h>` (Windows nerozlišuje velikost písmen) → `Lang.h`.
- **Nešlo přeložit `WebConfig.cpp`.** Pole `MR` kolidovalo s makrem z
  `xtensa/config/specreg.h` → popisné názvy. Krátké názvy velkými písmeny
  v tomhle projektu nepoužívat.

---

## [0.3.0]

Přenesení vychytávek z [petus/MeteoPlaneRadar](https://github.com/petus/MeteoPlaneRadar)
v0.4 – 0.5.2 na hardware ESPD‑3.5, plus vlastní vylepšení.

> ### ⚠️ Upozornění k aktualizaci
> Verze 0.3.0 mění **rozdělení paměti** (dvě aplikační oblasti, aby bylo kam
> nahrát bezdrátovou aktualizaci). Z verze 0.2 a nižší se na ni proto **nedá
> přejít přes OTA** — je nutné jednou nahrát `*.merged.bin` přes USB
> a v Arduino IDE zvolit **Partition Scheme = Custom**. Od 0.3.0 dál už
> aktualizace probíhá bezdrátově.

### Opraveno

- **Detail letadla se zavíral sám od sebe.** Příčinou nebyla data z adsb.fi, ale
  **vadná čtení z dotykového řadiče**. Knihovna `FT6236.cpp` čte z I2C bez
  kontroly návratových hodnot — když přenos selže, `Wire.read()` vrací `-1`,
  do bufferu se uloží `0xFF` a `getPoint()` pak vrátí bod s příznakem
  neplatnosti `z = 0`, který se po rotaci mapuje na **levý dolní roh (0, 320)**.
  Původní `Touch_Read()` příznak `z` ignoroval a hlásil to jako skutečné
  klepnutí mimo letadlo — tedy jako pokyn zrušit výběr.
  Nově se každý vzorek ověřuje: příznak platnosti, souřadnice uvnitř displeje,
  hodnota 4095 (otisk prázdné sběrnice) a nesmyslný skok během jednoho doteku
  (`TOUCH_MAX_JUMP_PX`). Počet zahozených čtení se při `TOUCH_DEBUG` vypisuje
  jednou za sekundu.
  Knihovna `FT6236.cpp` se záměrně nemění — LaskaKit ji distribuuje jako
  převzatou. Veškerá ochrana je v `Touch_FT6236.cpp`.
- **Poloviční provoz na I2C.** Místo dvou nezávislých transakcí za smyčku
  (`touched()` + `getPoint()`) se čte jen jednou. Kromě poloviční zátěže tím
  mizí i závod mezi oběma čteními.
- **Detail už neuskakuje při výpadku dat.** adsb.fi občas letadlo v jednom
  stažení vynechá a v dalším ho zase pošle. Nově se tolerují dvě po sobě jdoucí
  chybějící stažení (`DETAIL_GRACE_POLLS`), během nichž panel drží poslední
  známé hodnoty s poznámkou „signal ztracen".
- **Watchdog hlídá stav přihlášení.** Když `esp_task_wdt_add()` selhal, `Feed()`
  dál volal `reset()` na nepřihlášeném tasku a vypadalo to, že watchdog běží;
  `Resume()` mohl task přidat podruhé.
- **Opotřebení flash.** Změna rozsahu zapisovala do NVS okamžitě, takže rychlé
  přejíždění prstem přímo opotřebovávalo paměť. Nově se změny akumulují a
  zapíšou až po 2 s klidu (`Settings_Tick`).

### Přidáno

- **Obrazovka Nastavení** (třetí obrazovka): posuvník jasu, orientace mapy
  s kompasovým náhledem, přepínání jednotek, stav sítě, tlačítko WiFi + poloha
  a tlačítko Firmware update. Tlačítka sem přišla z pravého panelu obrazovky
  letadel, kde se tísnila v pruhu širokém 116 px.
- **Tlačítko továrního resetu** na obrazovce Nastavení. ESPD‑3.5 nemá žádné
  uživatelské tlačítko, takže reset nešlo vyvolat držením při startu jako
  u desek s BOOT. Tlačítko je menší, červené, vycentrované pod ostatními a
  odsazené, aby na něj nešla trefit ruka mířící na „Firmware update".
  Vyžaduje **dvě klepnutí** (první natáhne, druhé do `RESET_CONFIRM_MS`
  potvrdí); klepnutí kamkoli jinam ho zruší.
- **Klepatelné tečky přepínání obrazovek** (dole uprostřed). Dlouhý stisk je
  rychlý, ale není vidět — tečky ukazují, kde uživatel je, a zároveň slouží
  jako tlačítko pro skok na konkrétní obrazovku. Zóna je na všech obrazovkách
  volná a na radaru se pod ni nekreslí letadla.
- **Směrové přepínání obrazovek** dlouhým stiskem: levá polovina = předchozí,
  pravá = následující, dokola.
- **Dlouhý stisk na tlačítku v Nastavení provede tlačítko, ne přepnutí.** Bez
  toho by pomalejší stisk (nad 0,5 s) na „Firmware update" místo toho skočil na
  jinou obrazovku.
- **Aktualizace firmwaru přes WiFi (OTA, ElegantOTA).** Deska vytvoří AP, ukáže
  QR kód a firmware se nahraje z prohlížeče na `192.168.4.1/update`.
  Vyžaduje `src/partitions.csv` (dva app sloty po 6 MB).
  **Na rozdíl od zdrojového projektu se kreslí skutečný progress bar** — ten
  musel průběh vynechat a zhasínat podsvícení, protože jeho RGB panel si obraz
  průběžně čte z PSRAM a zápis do flash mu data odřezával. ILI9488 na SPI si
  obraz drží sám a data mu posílá tentýž task, který zapisuje flash, takže se
  nikdy nepřekrývají.
- **Orientace mapy** — v Nastavení řádek `Nahore` s tlačítky `−` / `+`, krok
  45°. Nastavuje se **směr, kterým se díváte z okna**, ne „o kolik mapu otočit".
  Otáčí se projekce, ne displej, takže se správně otočí i obrys, města a ikony
  letadel a dotykové souřadnice zůstávají platné. Vedle ovládání je kompasový
  náhled, po obvodu radaru značky S/V/J/Z. **Meteoradar se záměrně neotáčí** —
  srážková mapa se čte severem nahoru.
- **Zapamatování stavu UI** — poslední rozsah (zvlášť pro letadla a meteoradar)
  i naposledy zobrazená obrazovka se ukládají do NVS a obnoví se po restartu.
- **Zobrazení verze firmwaru** na obrazovce Nastavení, na OTA obrazovce a
  v sériovém výpisu. Nová sdílená hlavička `src/Version.h`.
- **Hodiny (NTP)** v pravém panelu obrazovky letadel — je tam na ně místo
  po přesunu tlačítek.
- **ICAO hex adresa** v detailu letadla — je to identita, podle které se
  letadlo drží mezi staženími.
- `sketch.yaml` (připnuté verze core i knihoven) a tento `CHANGELOG.md`.

### Změněno

- **Sjednocení nastavení do `src/Config.h`** — časová zóna, výchozí poloha,
  rozsahy obou obrazovek, intervaly stahování, název AP, `ADSB_MAX`,
  `WDT_TIMEOUT_S`, `DETAIL_GRACE_POLLS`, `MAP_ROT_STEP_DEG`, `OTA_IDLE_MS`
  a ladicí přepínač `TOUCH_DEBUG`. Rozsahy byly dřív zadrátované přímo
  v `ScreenPlanes.cpp` a `ScreenWeather.cpp`, `ADSB_MAX` v `ADSB.h`,
  výchozí poloha v `Settings.h`.
- **Při přetečení `ADSB_MAX` se drží nejbližší letadla, ne první v pořadí.**
  Dřív se při naplnění pole prostě skončilo, takže o tom, která letadla
  uvidíte, rozhodovalo pořadí v odpovědi serveru — u velkého rozsahu nad hustým
  provozem tak mohlo vypadnout letadlo přímo nad vámi.
- **Letadla na zemi se zahazují už při parsování**, aby nikdy nezabrala místo
  stroji ve vzduchu (u letiště by jinak dokázala zaplnit celý `ADSB_MAX`).
- **Ochrana proti nesmyslným souřadnicím** v ADS-B datech i v `Settings_SetLocation()`
  (mimo ±90 / ±180, nuly, NaN).
- **Diagnostické výpisy** u GeoIP (HTTP kód, chyba JSON, poloha mimo rozsah)
  a u připojení k WiFi.
- **Odstraněna veškerá obsluha tlačítka.** Původní kód počítal s tlačítkem
  na `BUTTON_PIN` (krátký stisk = rozsah, dlouhý = obrazovka, držení při startu
  = tovární reset), jenže ESPD‑3.5 žádné uživatelské tlačítko nemá. Ovládání je
  celé dotykové.
- Název konfiguračního AP zkrácen na `ESPD35-MeteoPlaneRadar` a čte se
  z `Config.h` i pro text na displeji, aby se nemusel hlídat na dvou místech.

---

## [0.2] a starší

Viz historie repozitáře. Radar letadel (adsb.fi) + animovaný srážkový
meteoradar ČHMÚ na displeji 480×320, port projektu petus/MeteoPlaneRadar.

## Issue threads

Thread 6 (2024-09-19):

Power button

sbur83, 2024-09-19:
I have uploaded to my espd-35 and now it powers on with power button and instantly powers off; I can hear it connect and disconnect when plugged into my computer. I see IO35 is connected to the power button as auto off on the schematic. Does this pin need to be set high or low or something on boot?

Konstantin-G, 2024-09-24:
So if you left that pin LOW in the program, it will turn off immediately, let it be set to HIGH at the beginning of setup()

Closed 2024-09-24.

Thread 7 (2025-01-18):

use of examples

gogela, 2025-01-18:
most examples use following backlight init code:
  ledcAttach(TFT_LED, 1000, 8);
  ledcWrite(1, TFT_LED_PWM);

causing example code won't work (display remains black) after Espressif arduino api commit 3c1e5a9 that changed parameters in ledcWrite .

according to Espressif doc https://espressif-docs.readthedocs-hosted.com/projects/arduino-esp32/en/latest/api/ledc.html
the ledcWrite has now parameters as follows:

void ledcWrite(uint8_t pin, uint32_t duty);

Using 1 as the 1st parameter causes PWM enabled on pin 1 not on TFT_LED (33)

simple modification to

ledcWrite(TFT_LED, TFT_LED_PWM);

solves the problem.

Konstantin-G, 2025-08-22:
All examples were updated

Closed 2025-08-22.

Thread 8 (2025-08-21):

Pin mappings for V2.1

golyalpha, 2025-08-21:
There seem to be different pin mappings between what's published as the V2 schematic, and what's on the V2.1 board - the most obvious one being that the auto power off pin is wired to IO17, instead of IO35. Not sure if there are other differences.

Also, since the split to V2/V3 in the header files, the provided V2 file is basically useless (misses most pin definitions that are available on the V2 boards, and used by the example sketches)

Konstantin-G, 2025-08-22:
Hi, thanks for comments.
I added more schematics and replace V2 file, Changes were made locally in library folder and forget to push to git

Closed 2025-08-22.

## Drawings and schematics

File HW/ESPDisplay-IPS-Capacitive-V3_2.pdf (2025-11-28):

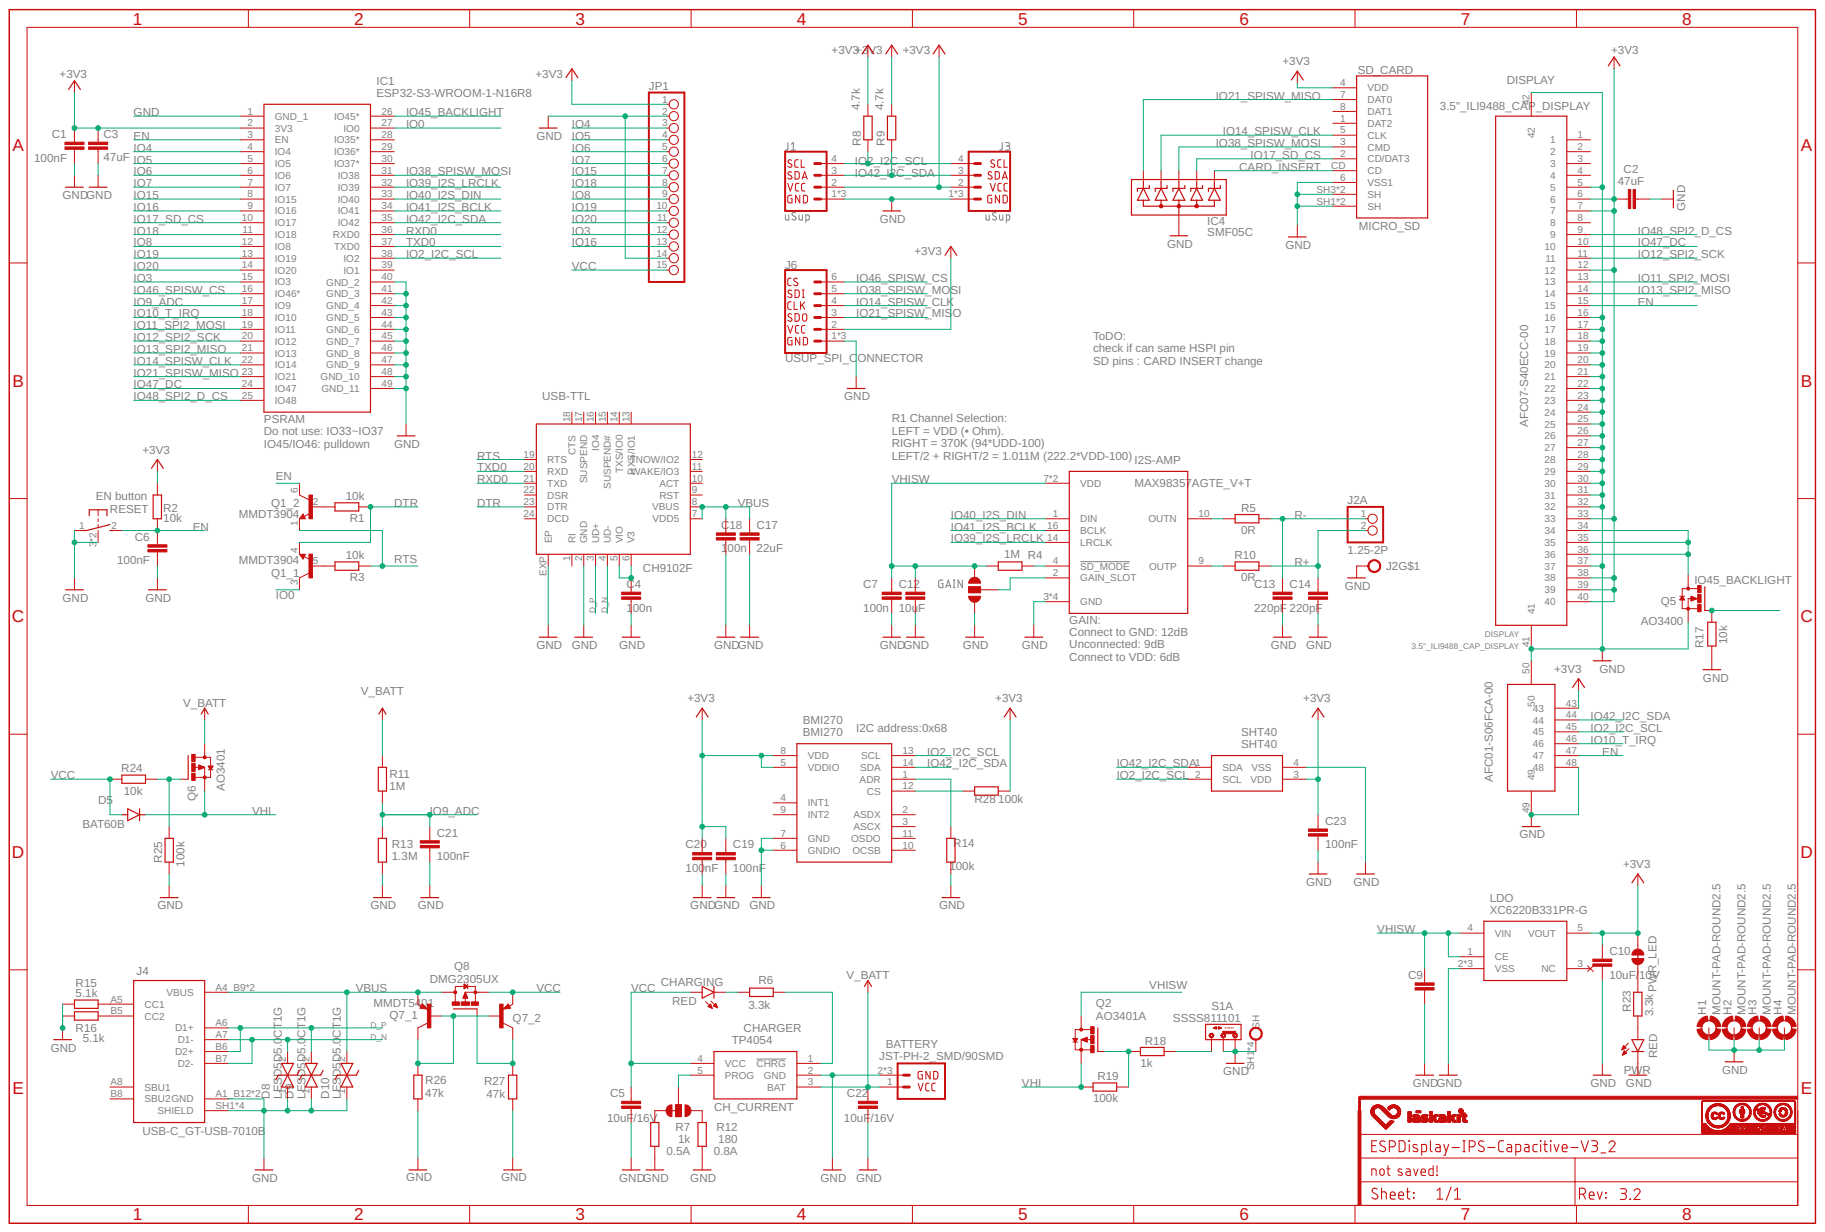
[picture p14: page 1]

R1 Channel Selection: LEFT = VDD (• Ohm). RIGHT = 370K (94*UDD-100) LEFT/2 + RIGHT/2 = 1.011M (222.2*VDD-100)

39
40

GAIN: Connect to GND: 12dB Unconnected: 9dB Connect to VDD: 6dB

MOUNT-PAD-ROUND2.5 MOUNT-PAD-ROUND2.5 GND

MOUNT-PAD-ROUND2.5

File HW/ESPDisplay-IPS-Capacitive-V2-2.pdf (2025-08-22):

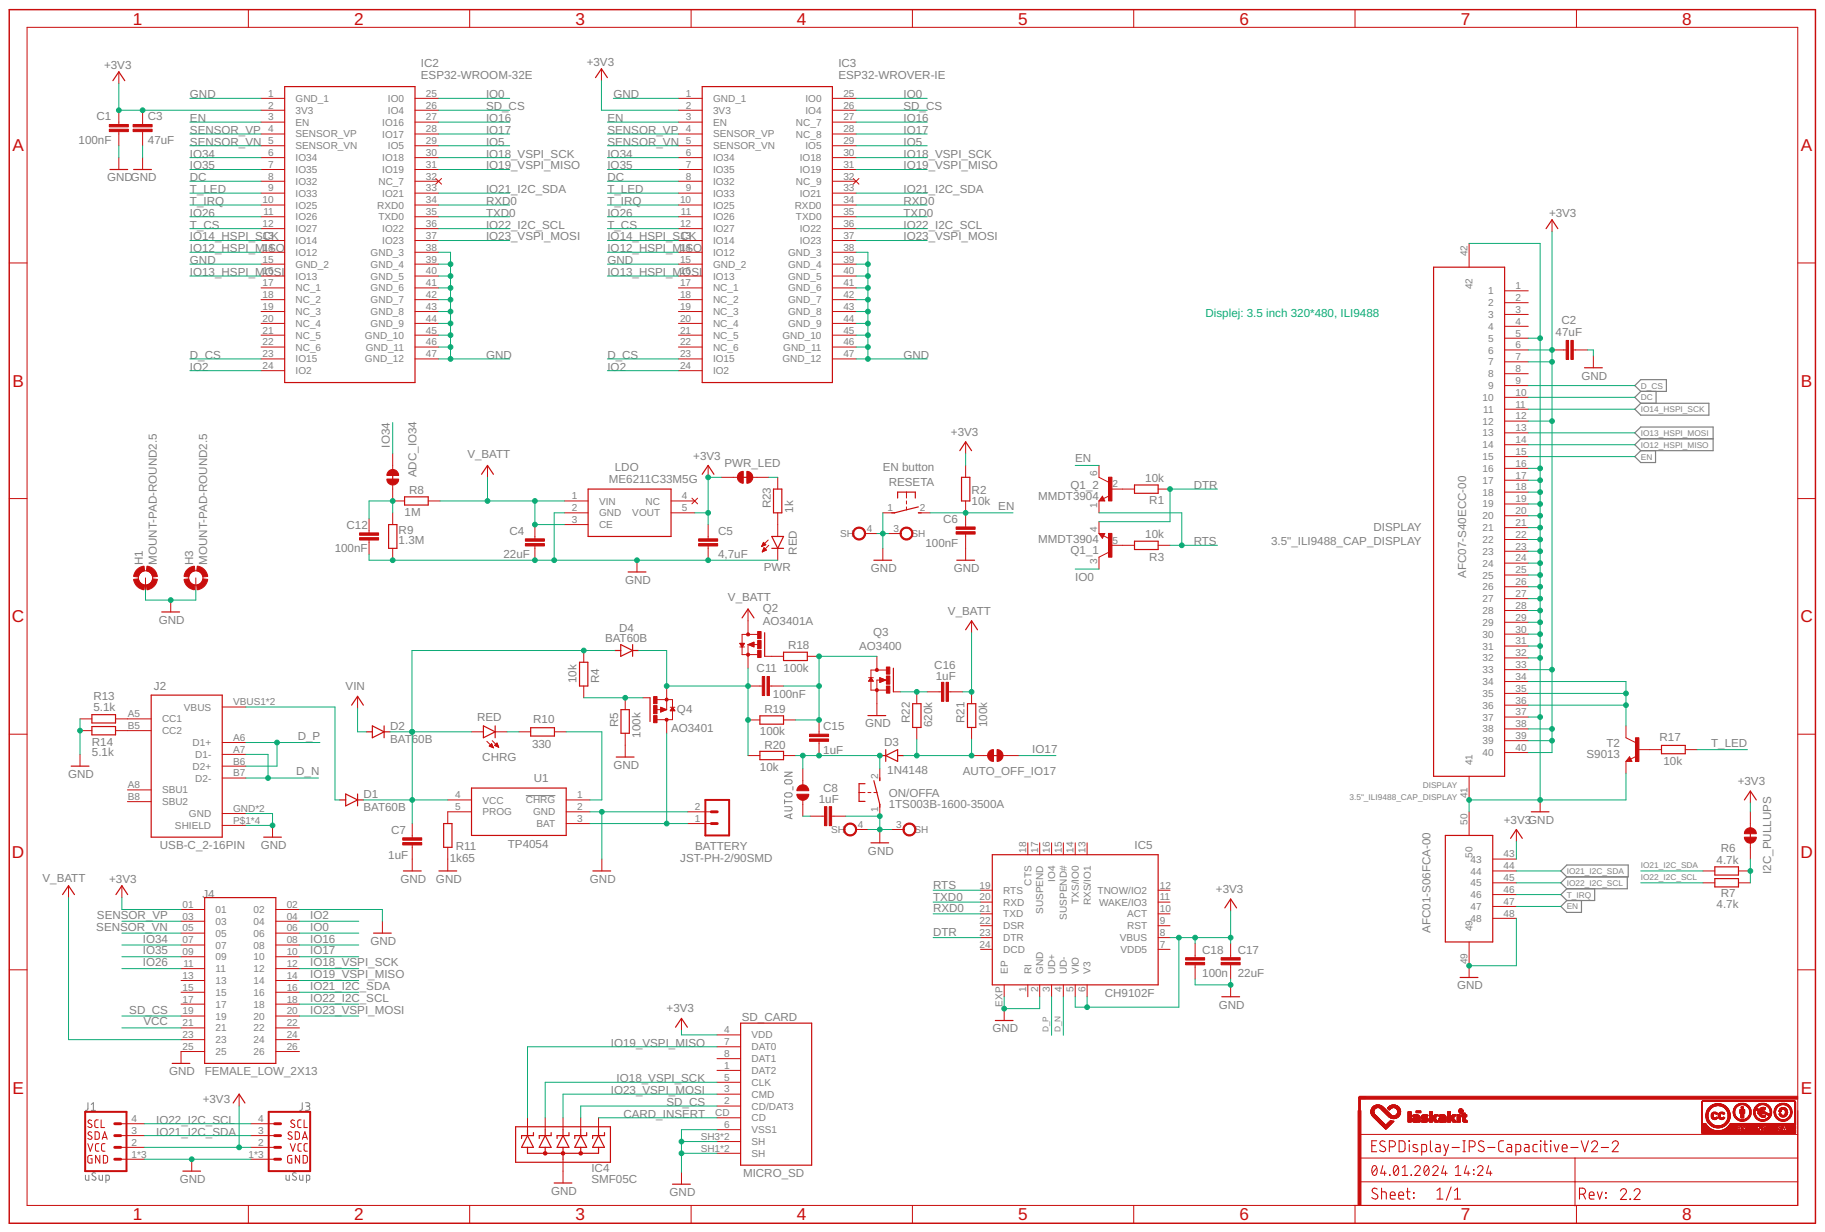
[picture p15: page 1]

10 | DC
11
12 | IO14_HSPI_SCK

14
15 | IO12_HSPI_MISO
16

34
35

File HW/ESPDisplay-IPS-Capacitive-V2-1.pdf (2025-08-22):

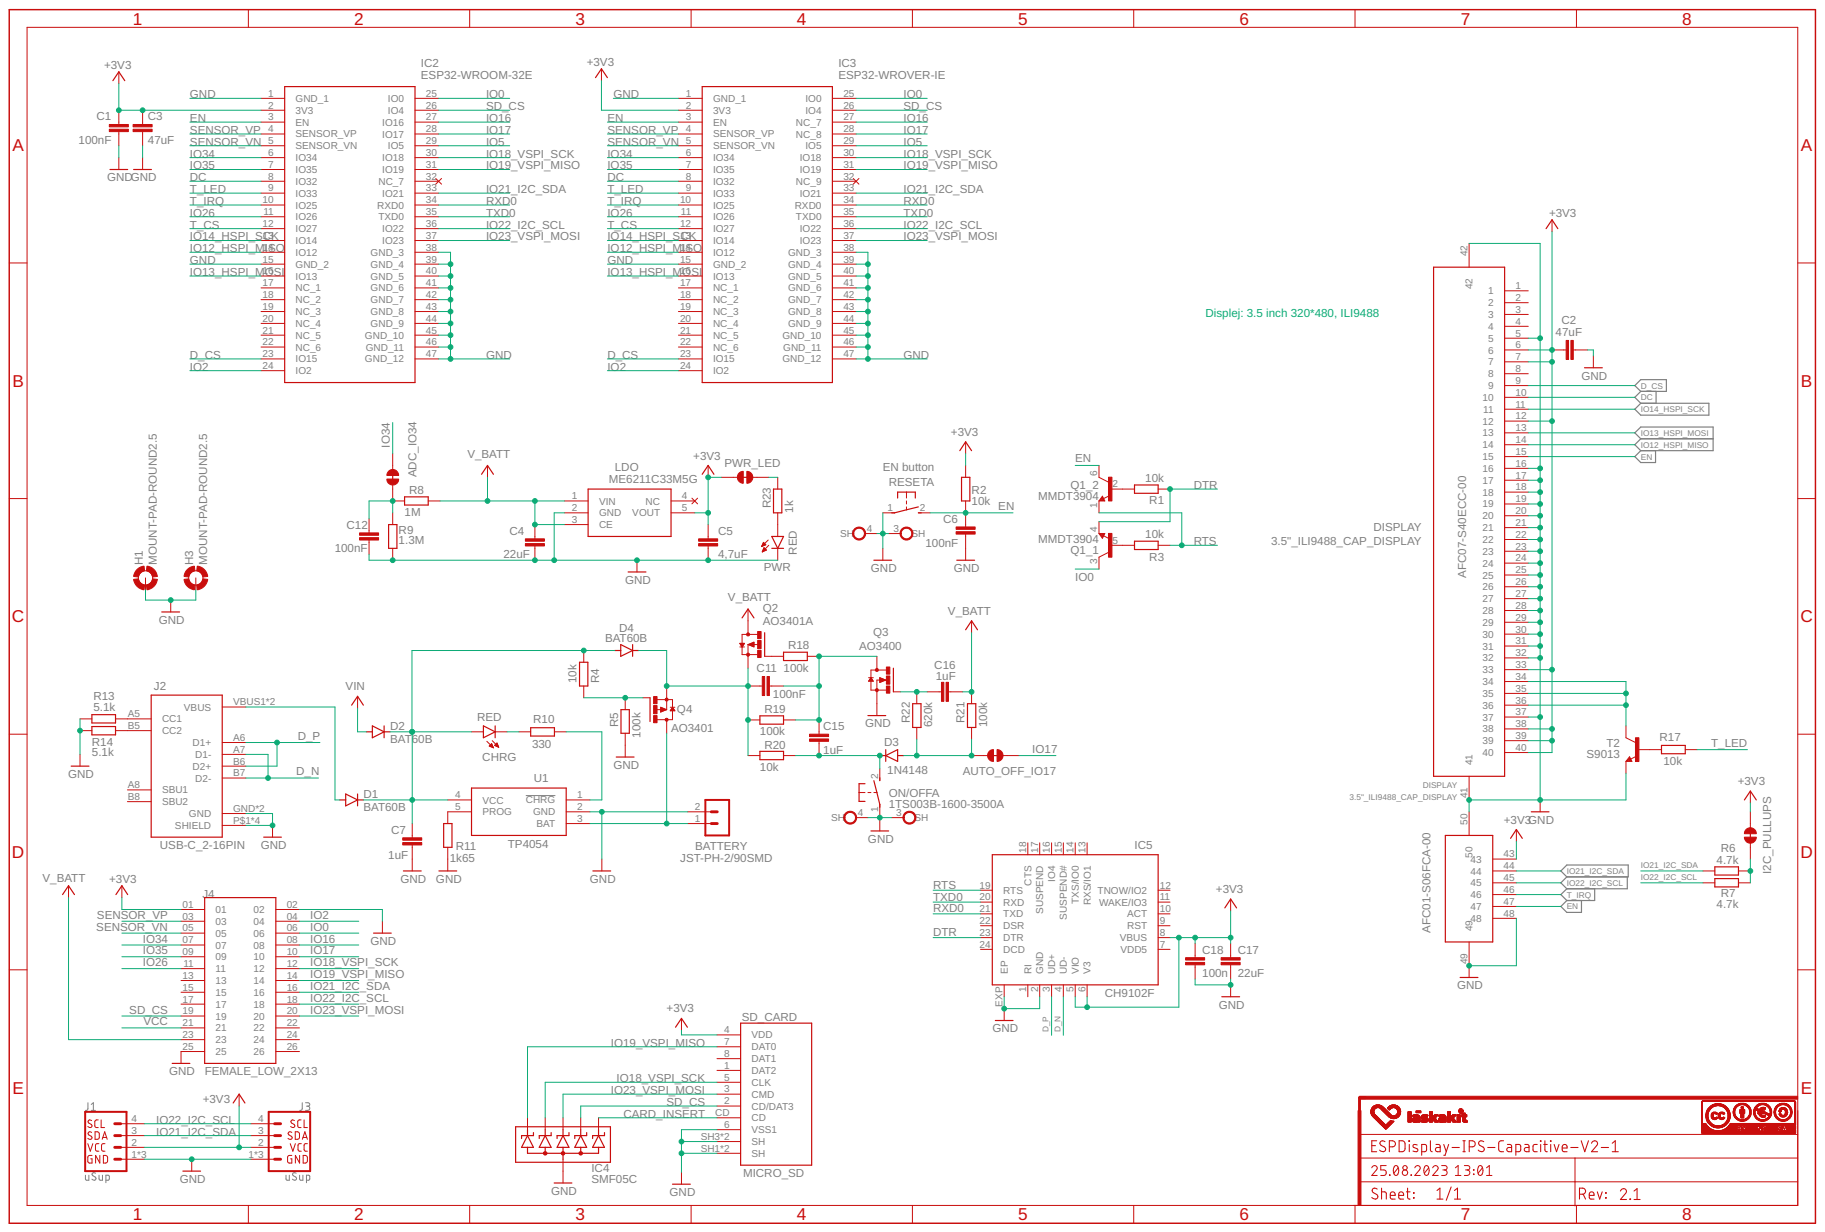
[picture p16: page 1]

10 | DC
11
12 | IO14_HSPI_SCK

14
15 | IO12_HSPI_MISO
16

34
35

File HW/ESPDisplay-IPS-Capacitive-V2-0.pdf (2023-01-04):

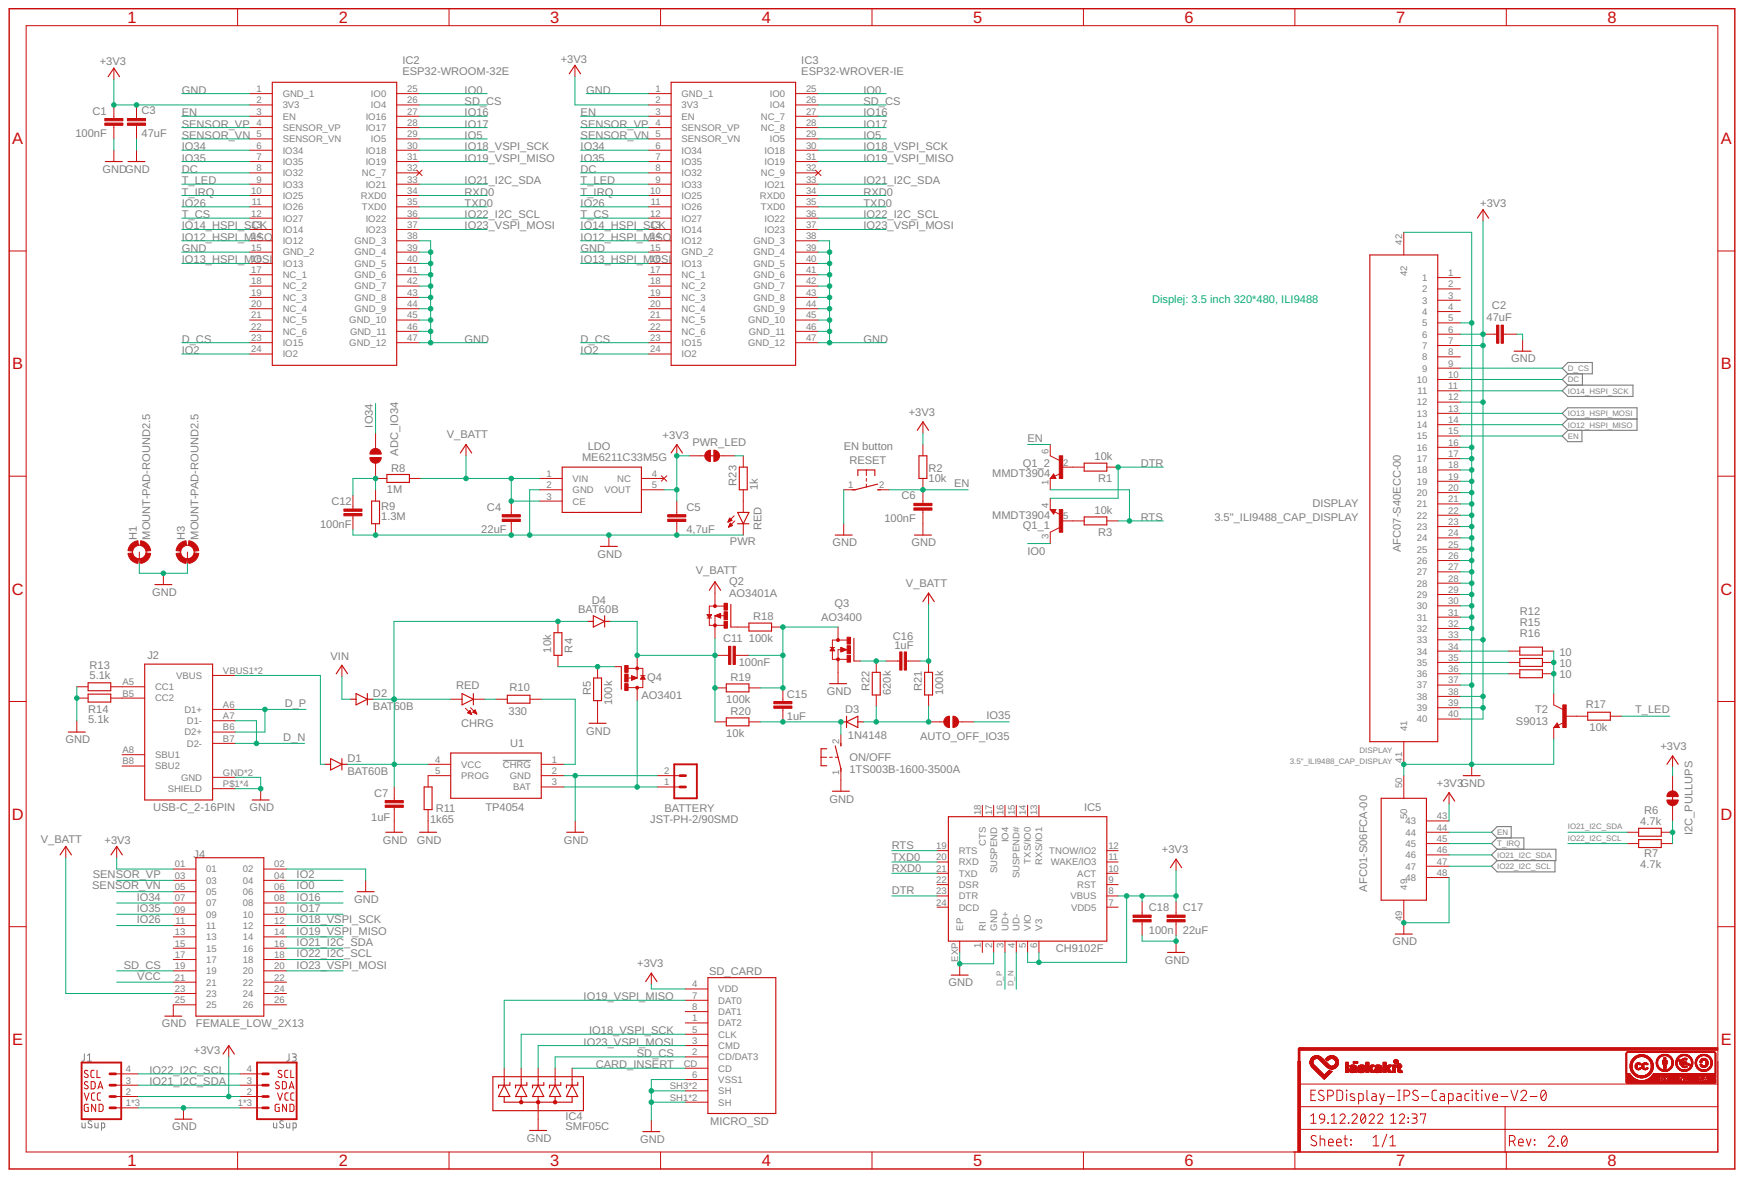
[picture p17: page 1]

10
11
12
13
14
15
16 | R12 R15 R16

34
35

3 IO21_I2C_SDA | 3

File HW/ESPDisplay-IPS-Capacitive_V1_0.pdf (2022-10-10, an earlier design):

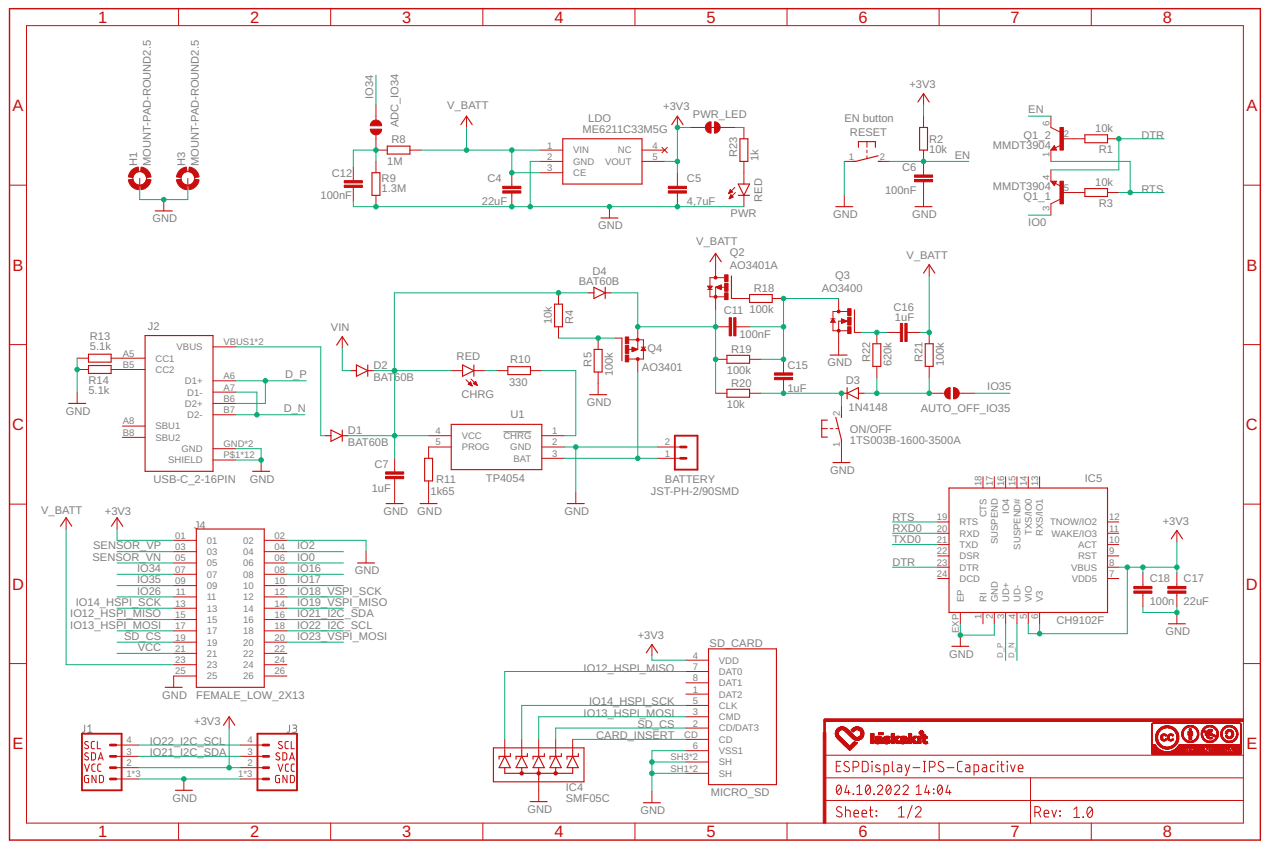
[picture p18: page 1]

3 IO21_I2C_SDA | 3

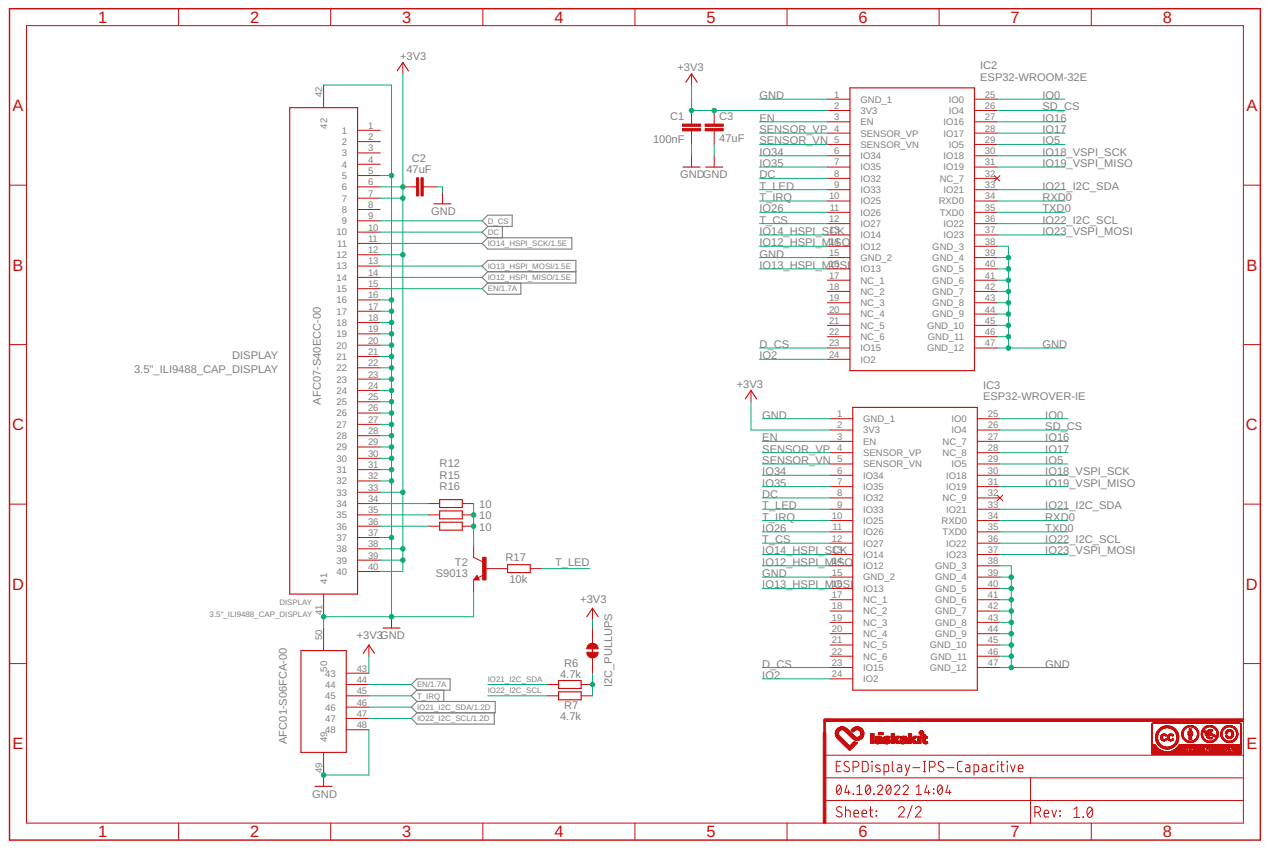
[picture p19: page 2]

AFC07-S40ECC-00 AFC01-S06FCA-00 +3V3GND 100nFGND 47uF 3.5"_ILI9488_CAP_DISPLAY 3.5"_ILI9488_CAP_DISPLAY ESP32-WROOM-32E ESP32-WROVER-IE +3V3 GND+3V3 101010 S9013 GND 10k +3V3 47uFGND 4.7k 4.7k+3V3 C1 C3 1 1 2 2 3 3 4 4 5 5 6 6 7 7 8 8 9 9 10 10 11 11 12 12 13 13 14 14 15 15 16 16 17 17 18 18 19 19 20 20 21 21 22 22 23 23 24 24 25 25 26 26 27 27 28 28 29 29 30 30 31 31 32 32 33 33 34 34 35 35 36 36 37 37 38 38 39 39 40 40 41 41 42 42 43 43 44 44 45 45 46 46 47 47 48 48 49 49 50 50 DISPLAY DISPLAY GND_1 1 3V3 2 EN 3 SENSOR_VP 4 SENSOR_VN 5 IO34 6 IO35 7 IO32 8 IO33 9 IO25 10 IO26 11 IO27 12 IO14 13 IO12 14 GND_2 15 IO13 16 NC_1 17 NC_2 18 NC_3 19 NC_4 20 NC_5 21 NC_6 22 IO15 23 IO2 24 IO0 25 IO4 26 IO16 27 IO17 28 IO5 29 IO18 30 IO19 31 NC_7 32 IO21 33 RXD0 34 TXD0 35 IO22 36 IO23 37 GND_3 38 GND_4 39 GND_5 40 GND_6 41 GND_7 42 GND_8 43 GND_9 44 GND_10 45 GND_11 46 GND_12 47 IC2 GND_1 1 3V3 2 EN 3 SENSOR_VP 4 SENSOR_VN 5 IO34 6 IO35 7 IO32 8 IO33 9 IO25 10 IO26 11 IO27 12 IO14 13 IO12 14 GND_2 15 IO13 16 NC_1 17 NC_2 18 NC_3 19 NC_4 20 NC_5 21 NC_6 22 IO15 23 IO2 24 IO0 25 IO4 26 NC_7 27 NC_8 28 IO5 29 IO18 30 IO19 31 NC_9 32 IO21 33 RXD0 34 TXD0 35 IO22 36 IO23 37 GND_3 38 GND_4 39 GND_5 40 GND_6 41 GND_7 42 GND_8 43 GND_9 44 GND_10 45 GND_11 46 GND_12 47 IC3 R12 R15 R16T2 R17 C2 R6 R7 I2C_PULLUPS GND GND GND GND GND GND IO13_HSPI_MOSI IO13_HSPI_MOSI IO13_HSPI_MOSI/1.5E T_CS T_CS DCDC DC IO5 IO5 D_CS D_CS D_CS T_IRQ T_IRQ T_IRQ SENSOR_VP SENSOR_VP SENSOR_VN SENSOR_VN IO34 IO34 IO35 IO35 T_LED T_LED T_LED IO26 IO26 IO23_VSPI_MOSI IO23_VSPI_MOSI IO22_I2C_SCL IO22_I2C_SCL IO22_I2C_SCL IO22_I2C_SCL/1.2D TXD0 TXD0 RXD0 RXD0 IO19_VSPI_MISO IO19_VSPI_MISO IO18_VSPI_SCK IO18_VSPI_SCK IO17 IO17 IO16 IO16 SD_CS SD_CS IO0 IO0 ENEN EN/1.7A EN/1.7A IO2 IO2 IO21_I2C_SDA IO21_I2C_SDA IO21_I2C_SDA IO21_I2C_SDA/1.2D IO12_HSPI_MISO IO12_HSPI_MISO IO12_HSPI_MISO/1.5E IO14_HSPI_SCK IO14_HSPI_SCK IO14_HSPI_SCK/1.5E ABCDE 1 2 3 4 5 6 7 8 ABCDE 1 2 3 4 5 6 7 8

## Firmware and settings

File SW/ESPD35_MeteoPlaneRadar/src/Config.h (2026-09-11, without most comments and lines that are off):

#pragma once
#include <Arduino.h>
#include "Version.h"   // FW_VERSION - jde do hlavicky User-Agent nize
#define LCD_WIDTH    480
#define LCD_HEIGHT   320
#define LCD_ROTATION 1        // 1 nebo 3 (podle orientace desky); 0/2 = na vysku
#define TFT_SCK    12
#define TFT_MOSI   11
#define TFT_MISO   13         // -1 pokud MISO neni potreba
#define TFT_CS     48
#define TFT_DC     47
#define TFT_RST    -1         // -1 pokud je RST na EN/napajeni
#define TFT_BL     45         // podsviceni (PWM)
#define TFT_SPI_HZ 40000000
#define RESET_CONFIRM_MS 6000UL
#define TOUCH_ENABLE     1     // 0 = dotyk vypnout (jen tlacitko)
#define I2C_SDA          42    // ESPD-3.5 v3 (ESP32-S3)
#define I2C_SCL          2     // ESPD-3.5 v3 (ESP32-S3)
#define TOUCH_INT        -1    // volitelne (polling ho nepotrebuje)
#define TOUCH_SENSITIVITY 40   // citlivost FT6236 (nizsi = citlivejsi)
#define TOUCH_ROTATION   3
#define TOUCH_MAX_JUMP_PX 160
#define TOUCH_RELEASE_MS 60
#define TOUCH_PUMP_MS 5
#define PANEL_W   124                          // sirka detailoveho panelu (~1/4)
#define MAP_W     (LCD_WIDTH - PANEL_W)        // sirka mapy (~3/4) = 356
#define MAP_H     LCD_HEIGHT                   // vyska mapy = 320
#define MAP_CX    (MAP_W / 2)                  // stred mapy X (poloha uzivatele)
#define MAP_CY    (MAP_H / 2)                  // stred mapy Y
#define R_RADIUS  (MAP_H / 2 - 8)
#define TZ_INFO    "CET-1CEST,M3.5.0,M10.5.0/3"
#define NTP_SERVER "pool.ntp.org"
#define DEFAULT_LAT 50.0755
#define DEFAULT_LON 14.4378
#define AP_SSID     "ESPD35-MeteoPlaneRadar"
#define AP_PASSWORD ""     // "" = otevrena sit
#define ADSB_MAX 100       // strop letadel drzenych/kreslenych (jen ve vzduchu)
#define PLANE_RANGES_KM { 10.0f, 25.0f, 50.0f, 100.0f }
#define ADSB_PERIOD_NEAR_MS  5000    // do  ADSB_NEAR_KM
#define ADSB_PERIOD_MID_MS  10000    // do  ADSB_MID_KM
#define ADSB_PERIOD_FAR_MS  15000    // nad ADSB_MID_KM
#define ADSB_NEAR_KM 25.0f
#define ADSB_MID_KM  50.0f
#define METEO_RANGES_KM { 25.0f, 50.0f, 100.0f, 200.0f, 0.0f }
#define DETAIL_GRACE_POLLS 2
#define MAP_ROT_STEP_DEG 45    // stupnu na jeden stisk (45 -> osm poloh)
#define OTA_IDLE_MS 300000UL   // po teto dobe bez nahravani se rezim OTA ukonci
#define WDT_TIMEOUT_S 20       // restart po tolika sekundach zaseknuti
#define NET_MIN_HEAP 60000
#define NET_TLS_HANDSHAKE_S 8
#define NET_BODY_BUDGET_MS 15000UL
#define HTTP_USER_AGENT "ESPD35_MeteoPlaneRadar/" FW_VERSION " (+https://chiptron.cz)"
#define SQUAWK_HIJACK "7500"
#define SQUAWK_RADIO  "7600"
#define SQUAWK_EMERG  "7700"
#define BRIGHT_DAY_DEFAULT     80   // %
#define BRIGHT_NIGHT_DEFAULT   25   // %
#define NIGHT_OFFSET_MIN_LIMIT 120  // +/- minut kolem vychodu a zapadu
#define ALT_MIN_FT_DEFAULT      0
#define ALT_MAX_FT_DEFAULT  60000   // nad tim uz nic bezne nelita
#define LAYOUT_DEBUG 0
#define TOUCH_DEBUG 0
#define WEB_PORT       80
#define WEB_HOSTNAME   "espd35meteoradar"   // -> http://espd35meteoradar.local/
#define WEB_ADMIN_USER "admin"
#define WIFI_CONNECT_TIMEOUT_MS 20000UL
#define WIFI_RETRY_MS           15000UL
#define SCREEN_CLOCK_I    0
#define SCREEN_PLANES_I   1
#define SCREEN_METEO_I    2
#define SCREEN_FORECAST_I 3
#define SCREEN_SETTINGS_I 4
#define SCREEN_N          5
#define AUTO_ROTATE_PAUSE_MS 600000UL
#define FORECAST_URL   "https://api.open-meteo.com/v1/forecast"
#define AIRQUALITY_URL "https://air-quality-api.open-meteo.com/v1/air-quality"
#define GEOCODE_URL    "https://geocoding-api.open-meteo.com/v1/search"
#define FORECAST_HOURS 6        // hodinove sloupce (480 / 6 = 80 px na sloupec)
#define FORECAST_DAYS  3        // denni radky pod nimi
#define FORECAST_PERIOD_MS 1800000UL   // 30 min
#define FORECAST_RETRY_MS   120000UL   // 2 min po neuspechu
#define AQ_PERIOD_MS 1800000UL
#define AQ_RETRY_MS   120000UL
#define OUTSIDE_DEG_SYMBOL 0
#if OUTSIDE_DEG_SYMBOL
  #define OUTSIDE_DEG_TEXT "\xB0C"
#else
  #define OUTSIDE_DEG_TEXT "degC"
#endif
#define ROUTE_API_BASE "https://api.adsb.lol/api/0/route"
#define ROUTE_CACHE_N  8      // zapamatovanych odpovedi
#define SEC_STYLE_OFF   0
#define SEC_STYLE_DOTS  1     // 60 znacek po elipse
#define SEC_STYLE_LINE  2     // "Cara" - plny oblouk od dvanactky
#define SEC_STYLE_COMET 3     // "Kometa" - bezec s dohasinajicim ohonem
#define CLK_SEC_TH        4   // tloustka behu sekund v px
#define CLK_SEC_INSET_X  16   // odsazeni elipsy od leveho a praveho kraje
#define CLK_SEC_INSET_Y  16   // odsazeni od horniho a dolniho kraje
#define CLK_COMET_TAIL_SEC 20
#define CZ_VIEW_LAT       49.805f
#define CZ_VIEW_LON       15.475f
#define CZ_VIEW_RADIUS_KM 260.0f

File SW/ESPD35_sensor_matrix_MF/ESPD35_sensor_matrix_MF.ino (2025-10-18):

/* ESPD-3.5" - used for automatic regulation of light and measurement of
 * CO2, temperature, humidity and light For Maker Faire
 * Written by chiptron.cz for laskakit.cz (2023)
 * 
 * How to steps:
 * 1. Copy file from https://github.com/LaskaKit/ESPD-35/tree/main/SW to Arduino/libraries/TFT_eSPI/User_Setups/
 *    - for version v2.3 and before:  Setup300_ILI9488_ESPD-3_5_v2.h 
 *    - for version v3 and above:     Setup303_ILI9488_ESPD-3_5_v3.h
 * 2. in Arduino/libraries/TFT_eSPI/User_Setup_Select.h 
      a. comment: #include <User_Setup.h> 
      b. add: 
          - for version v2.3 and before:  #include <User_Setups/Setup300_ILI9488_ESPD-3_5_v2.h>  // Setup file for LaskaKit ESPD-3.5" 320x480, ILI9488 
          - for version v3 and above:     #include <User_Setups/Setup303_ILI9488_ESPD-3_5_v3.h>  // Setup file for LaskaKit ESPD-3.5" 320x480, ILI9488 V3
 * 
 * Board constants:
      TFT_BL          - LED back-light use: analogWrite(TFT_BL, TFT_BL_PWM);
      POWER_OFF_PIN   - Pull LOW to switch board off
      TOUCH_INT       - Touch interrupt pin
    * I2C (µŠup and devices (only from v3)):
      I2C_SDA         - Data pin 
      I2C_SCL         - Clock pin
    * SPI (µŠup (only from v3) and SD card):
      SPI_MISO        - MISO pin
      SPI_MOSI        - MOSI pin
      SPI_SCK         - Clock pin
      SPI_USUP_CS     - µŠup Chip Select pin (only from v3)
      SPI_SD_CS       - SD Card Chip Select pin
    * I2S (only from v3):
      I2S_LRC         - Word select a.k.a. left-right clock pin
      I2S_DOUT        - Serial data pin
      I2S_BCLK        - Serial clock a.k.a. bit clock pin
    * Battery mesurement:
      BAT_PIN         - Battery voltage mesurement
      deviderRatio    - Voltage devider ratio on ADC pin 1MOhm + 1.3MOhm
 *
 * Used library:
 * TFT_eSPI - https://github.com/Bodmer/TFT_eSPI
 * TSL2561 https://github.com/adafruit/Adafruit_TSL2561/
 * SCD41 - https://github.com/sparkfun/SparkFun_SCD4x_Arduino_Library
 * SEN66 - https://github.com/Sensirion/arduino-i2c-sen66
 * Email:podpora@laskakit.cz
 * Web:laskakit.cz
*/


#include <WiFi.h>

// TFT Display
#include <TFT_eSPI.h>  // Hardware-specific library
#include <SPI.h>

// SCD41
#include "SparkFun_SCD4x_Arduino_Library.h"

// TSL2561
#include <Adafruit_Sensor.h>
#include <Adafruit_TSL2561_U.h>

// SEN66
#include <SensirionI2cSen66.h>

// BMP280
#include <Adafruit_Sensor.h>
#include <Adafruit_BMP280.h>

// SHT40
#include "Adafruit_SHT4x.h"

// LTR390
#include "Adafruit_LTR390.h"

// Fonts
#include "OpenSansSB_14px.h"
#include "OpenSansSB_20px.h"
#include "OpenSansSB_40px.h"
#include "OpenSansSB_60px.h"
#include "DSEG14Classic_100px_bold.h"
#include "DSEG14Classic_80px_bold.h"
#include "DSEG14Classic_60px_bold.h"


#include <TFT_eSPI.h>
#include <math.h>

TFT_eSPI tft = TFT_eSPI();

#define DEG2RAD 0.0174532925

// sensors enabled
bool tsl2561_en = true;
bool scd41_en = true;
bool sen66_en = true;
bool bmp280_en = true;
bool sht40_en = false;
bool ltr390_en = true;

// TSL2561
Adafruit_TSL2561_Unified tsl = Adafruit_TSL2561_Unified(TSL2561_ADDR_FLOAT, 12345);
uint16_t TSL2561_light = 0;
uint16_t TSL2561_broadband = 0;
uint16_t TSL2561_ir = 0;

// SCD41
SCD4x SCD41;
int SCD41_CO2 = 0;
float SCD41_temperature = 0.0;
int SCD41_humidity = 0;

// SEN66
SensirionI2cSen66 sensor;
static int16_t error;
#define NO_ERROR 0
float SEN66_massConcentrationPm1p0 = 0.0;
float SEN66_massConcentrationPm2p5 = 0.0;
float SEN66_massConcentrationPm4p0 = 0.0;
float SEN66_massConcentrationPm10p0 = 0.0;
float SEN66_humidity = 0.0;
float SEN66_temperature = 0.0;
float SEN66_vocIndex = 0.0;
float SEN66_noxIndex = 0.0;
uint16_t SEN66_CO2 = 0;

// BMP280
Adafruit_BMP280 bmp; // I2C
float BMP280_pressure = 0.0;

// SHT40
Adafruit_SHT4x sht4 = Adafruit_SHT4x();
sensors_event_t SHT40_temperature, SHT40_humidity;

// LTR390
Adafruit_LTR390 ltr = Adafruit_LTR390();
uint16_t ltr390_uv = 0;

struct Gauge {
  int x, y, r;
  float value;        // aktuální hodnota 0–100
  int targetValue;    // cílová hodnota 0–100
  int realValue;      // původní hodnota 0–1000
  float lastValue;    // předchozí hodnota ručičky
  const char* label;
  const char* units;
};

const char* gaugeLabels[6] = {
  "Teplota",
  "Vlhkost",
  "CO2",
  "Pev. cast.",
  "Osvetleni",
  "UV"
};

const char* gaugeUnits[6] = {
  "degC",
  "%Rh",
  "ppm",
  "ug/m3",
  "lux",
  "-"
};

Gauge gauges[6]; // místo samostatných polí

void drawNeedle(Gauge& g, uint16_t color) {
  float angleDeg = map(g.value, 0, 100, 180, 360);
  float angleRad = angleDeg * DEG2RAD;
  int x2 = g.x + cos(angleRad) * (g.r - 12);
  int y2 = g.y + sin(angleRad) * (g.r - 12);
  tft.drawLine(g.x, g.y, x2, y2, color);
}

void drawGaugeStatic(Gauge& g) {
  tft.setTextDatum(MC_DATUM);
  tft.setTextColor(TFT_WHITE, TFT_BLACK);

  // Nadpis
  tft.setFreeFont(&OpenSansSB_20px);
  tft.drawString(g.label, g.x, g.y - g.r - 20);
  tft.setTextFont(2);

  // Polokruh
  for (int angle = 180; angle <= 360; angle++) {
    float rad = angle * DEG2RAD;
    int x1 = g.x + cos(rad) * g.r;
    int y1 = g.y + sin(rad) * g.r;
    tft.drawPixel(x1, y1, TFT_WHITE);
  }

  // Rysky
  for (int i = 180; i <= 360; i += 30) {
    float angle = i * DEG2RAD;
    int x1 = g.x + cos(angle) * (g.r - 10);
    int y1 = g.y + sin(angle) * (g.r - 10);
    int x2 = g.x + cos(angle) * g.r;
    int y2 = g.y + sin(angle) * g.r;
    tft.drawLine(x1, y1, x2, y2, TFT_WHITE);
  }

  // Min a max
  tft.setTextDatum(CL_DATUM);
  tft.drawString("MIN", g.x - g.r, g.y + 5);
  tft.setTextDatum(CR_DATUM);
  tft.drawString("MAX", g.x + g.r, g.y + 5);

}

void drawGaugeValue(const Gauge& g) {
  tft.setFreeFont(&OpenSansSB_20px); 
  char buf[10];
  sprintf(buf, "%d", g.realValue);
  tft.setTextDatum(MC_DATUM);
  tft.setTextColor(TFT_WHITE, TFT_BLACK);
  tft.drawString(buf, g.x, g.y + g.r - 25);
  tft.setTextFont(2);
  //sprintf(buf, "%s", g.units);
  tft.drawString(g.units, g.x, g.y + g.r - 5);
}

void setup() {

  Serial.begin(115200);
  delay(2000);

  Wire.begin(I2C_SDA, I2C_SCL);

  scd41_init();

  tsl2561_init();

  sen66_init();

  bmp280_init();

  sht40_init();

  ltr390_init();

  tft.init();
  tft.setRotation(0); // orientace na výšku (320x480)
  tft.fillScreen(TFT_BLACK);
  tft.setTextFont(2); // volitelně: jiný font

  int cols = 2;
  int rows = 3;
  int radius = 50;
  int xSpacing = 320 / cols;
  int ySpacing = 480 / rows;

  for (int i = 0; i < 6; i++) {
    int col = i % cols;
    int row = i / cols;

    gauges[i].x = xSpacing * col + xSpacing / 2;
    gauges[i].y = ySpacing * row + ySpacing / 2 + 25;
    gauges[i].r = radius;
    gauges[i].value = 0;
    gauges[i].targetValue = 0;
    gauges[i].realValue = 0;
    gauges[i].lastValue = 0;
    gauges[i].label = gaugeLabels[i];
    gauges[i].units = gaugeUnits[i];

    drawGaugeStatic(gauges[i]); // vykreslí rámeček, stupnici, texty
    drawNeedle(gauges[i], TFT_RED); // první ručička
  }
}

void loop() {
  static unsigned long lastUpdate = 0;
  static unsigned long lastDraw = 0;
  static unsigned long lastFullRefresh = 0;

  if (millis() - lastUpdate > 60000) {
    lastUpdate = millis();

    tft.fillScreen(TFT_BLACK);
    
    int cols = 2;
    int rows = 3;
    int radius = 50;
    int xSpacing = 320 / cols;
    int ySpacing = 480 / rows;

    for (int i = 0; i < 6; i++) {
      int col = i % cols;
      int row = i / cols;

      gauges[i].x = xSpacing * col + xSpacing / 2;
      gauges[i].y = ySpacing * row + ySpacing / 2 + 25;
      gauges[i].r = radius;
      gauges[i].value = 0;
      gauges[i].targetValue = 0;
      gauges[i].realValue = 0;
      gauges[i].lastValue = 0;
      gauges[i].label = gaugeLabels[i];
      gauges[i].units = gaugeUnits[i];

      drawGaugeStatic(gauges[i]); // vykreslí rámeček, stupnici, texty
      drawNeedle(gauges[i], TFT_RED); // první ručička
    }

  }

  if (millis() - lastFullRefresh > 3000) {
    lastFullRefresh = millis();

    if (tsl2561_en == true) {
      tsl2561_measure();
      gauges[4].realValue = TSL2561_light;                     // 0–1200
      gauges[4].targetValue = map(gauges[4].realValue, 0, 5000, 0, 100);  // 0–100 %
    }

    if (bmp280_en == true){
      bmp280_measure();
      gauges[5].realValue = BMP280_pressure;                     // 0–5000
      gauges[5].targetValue = map(gauges[5].realValue, 0, 1200, 0, 100);  // 0–100 %
    }

    if(ltr390_en == true){
      ltr390_measure();
      gauges[5].realValue = ltr390_uv;                     // 0-2300
      gauges[5].targetValue = map(gauges[5].realValue, 0, 2300, 0, 100);  // 0–100 %
    } 

    if (sht40_en == true)
    {
      sht40_measure();
      gauges[0].realValue = SHT40_temperature.temperature;                     // 50
      gauges[0].targetValue = map(gauges[0].realValue, 0, 50, 0, 100);  // 0–100 %

      gauges[1].realValue = SHT40_humidity.relative_humidity;                     // 100
      gauges[1].targetValue = map(gauges[1].realValue, 0, 100, 0, 100);  // 0–100 %
    }
    if (scd41_en == true) {
      scd41_measure();
      gauges[2].realValue = SCD41_CO2;                     // 0–5000
      gauges[2].targetValue = map(gauges[2].realValue, 0, 5000, 0, 100);  // 0–100 %
    }
    if (sen66_en == true){
      sen66_measure();
      gauges[0].realValue = SEN66_temperature;                     // 0–5000
      gauges[0].targetValue = map(gauges[0].realValue, 0, 50, 0, 100);  // 0–100 %

      gauges[1].realValue = SEN66_humidity;                     // 0–5000
      gauges[1].targetValue = map(gauges[1].realValue, 0, 100, 0, 100);  // 0–100 %

      gauges[2].realValue = SEN66_CO2;                     // 0–5000
      gauges[2].targetValue = map(gauges[2].realValue, 0, 3000, 0, 100);  // 0–100 %

      gauges[3].realValue = SEN66_massConcentrationPm10p0;                     // 0–5000
      gauges[3].targetValue = map(gauges[3].realValue, 0, 250, 0, 100);  // 0–100 %

    }
  }

  if (millis() - lastDraw > 50) {
    lastDraw = millis();

    for (int i = 0; i < 6; i++) {
      Gauge& g = gauges[i];

      // SMAŽ STAROU RUČIČKU
      drawNeedle(g, TFT_BLACK);

      // INTERPOLUJ NOVOU HODNOTU
      float diff = g.targetValue - g.value;
      if (abs(diff) > 0.5)
        g.value += diff * 0.1;
      else
        g.value = g.targetValue;

      // NAKRESLI NOVOU RUČIČKU
      drawNeedle(g, TFT_RED);

      // Zobrazit hodnotu pod budíkem
      drawGaugeValue(g);
    }
  }
}

void ltr390_init(){
    if ( ! ltr.begin() ) {
    Serial.println("ltr390 init");
    ltr390_en = false;
  }

  if(ltr390_en == true){
    ltr.setMode(LTR390_MODE_UVS);
    ltr.setGain(LTR390_GAIN_3);
    ltr.setResolution(LTR390_RESOLUTION_16BIT);
    ltr.setThresholds(100, 1000);
    ltr.configInterrupt(true, LTR390_MODE_UVS);
  }
}

void ltr390_measure(){
    if (ltr.newDataAvailable()) {
      ltr390_uv = ltr.readUVS();
      Serial.print("LTR390 [UV]: "); Serial.println(ltr390_uv);
  }
}

void sht40_init(){
    if (! sht4.begin()) {
    Serial.println("sht40 init");
    sht40_en = false;
  }

  if(sht40_en == true)
  {
    sht4.setPrecision(SHT4X_HIGH_PRECISION);
    sht4.setHeater(SHT4X_NO_HEATER);
  }
}

void sht40_measure(){
  if(sht40_en == true){
    sht4.getEvent(&SHT40_humidity, &SHT40_temperature);

    Serial.print("SHT40 [temperature]: "); Serial.println(SHT40_temperature.temperature);
    Serial.print("SHT40 [humidity]: "); Serial.println(SHT40_humidity.relative_humidity);
  }
}

void bmp280_init(){
  if (!bmp.begin(0x77)) {  // Adresa může být 0x76 nebo 0x77
    Serial.println("bmp280 init");
    bmp280_en = false;
  }
  if(bmp280_en == true)
  {
    bmp.setSampling(
    Adafruit_BMP280::MODE_NORMAL,
    Adafruit_BMP280::SAMPLING_X2,   // Teplota
    Adafruit_BMP280::SAMPLING_X16,  // Tlak
    Adafruit_BMP280::FILTER_X16,
    Adafruit_BMP280::STANDBY_MS_500
  );
  }
}
void bmp280_measure(){
  if(bmp280_en == true)
  {
    BMP280_pressure = bmp.readPressure() / 100.0F;   // hPa
    Serial.print("BMP280 [pressure]: "); Serial.println(BMP280_pressure);
  }
}

void sen66_init(){
  sensor.begin(Wire, SEN66_I2C_ADDR_6B);
  error = sensor.deviceReset();
  if (error != NO_ERROR) 
  {
    sen66_en = false;
    Serial.print("sen66 init");
  }
  if(sen66_en == true)
  {
    sensor.startContinuousMeasurement();
  }
}

void sen66_measure(){
  error = sensor.readMeasuredValues(
        SEN66_massConcentrationPm1p0, SEN66_massConcentrationPm2p5, SEN66_massConcentrationPm4p0,
        SEN66_massConcentrationPm10p0, SEN66_humidity, SEN66_temperature, SEN66_vocIndex, SEN66_noxIndex,
        SEN66_CO2);

        Serial.print("SEN66 [PM10]: "); Serial.println(SEN66_massConcentrationPm10p0);
        Serial.print("SEN66 [CO2]: "); Serial.println(SEN66_CO2);
        Serial.print("SEN66 [temperature]: "); Serial.println(SEN66_temperature);
        Serial.print("SEN66 [humidity]: "); Serial.println(SEN66_humidity);
        Serial.print("SEN66 [NOX index]: "); Serial.println(SEN66_noxIndex);
        Serial.print("SEN66 [VOC index]: "); Serial.println(SEN66_vocIndex);

        /*SEN66_humidity = 0.0;
        SEN66_temperature = 0.0;*/
        if(SEN66_massConcentrationPm10p0 == 6553.50)
        {
          SEN66_massConcentrationPm1p0 = 0.0;
          SEN66_massConcentrationPm2p5 = 0.0;
          SEN66_massConcentrationPm4p0 = 0.0;
          SEN66_massConcentrationPm10p0 = 0.0;
        }


        if(SEN66_CO2 == 65535){
          SEN66_vocIndex = 0.0;
          SEN66_noxIndex = 0.0;
          SEN66_CO2 = 0;
        }

}

void tsl2561_init() {
  if (!tsl.begin()) {
    tsl2561_en = false;
    Serial.println("tsl2561 init");
  }
  if (tsl2561_en == true) {
    tsl.enableAutoRange(true);                              // Automatický rozsah
    tsl.setIntegrationTime(TSL2561_INTEGRATIONTIME_101MS);  // Kratší doba integrace
  }
}
void tsl2561_measure() {
  sensors_event_t event;
  tsl.getEvent(&event);
  //Serial.println("tsl2561_measure");
  if (event.light) {
    // Čtení aktuální intenzity světla
    TSL2561_light = event.light;
    Serial.print("TSL2561 [light]: "); Serial.println(TSL2561_light);
  }

  tsl.getLuminosity(&TSL2561_broadband, &TSL2561_ir);
  Serial.print("TSL2561 [visible + IR]: "); Serial.println(TSL2561_broadband);
  Serial.print("TSL2561 [IR]: "); Serial.println(TSL2561_ir);
}

void scd41_init() {
  if (SCD41.begin(true, false) == false) {
    scd41_en = false;
    Serial.println("scd41 init");
  }
}
void scd41_measure() {
  if (SCD41.readMeasurement())  // wait for a new data (approx 30s)
  {
    SCD41_CO2 = SCD41.getCO2();
    SCD41_temperature = SCD41.getTemperature();
    SCD41_humidity = SCD41.getHumidity();

    Serial.print("SCD41 [CO2]: "); Serial.println(SCD41_CO2);
    Serial.print("SCD41 [temperature]: "); Serial.println(SCD41_temperature);
    Serial.print("SCD41 [humidity]: "); Serial.println(SCD41_humidity);
  }
}



#if 0
// TFT display
TFT_eSPI tft = TFT_eSPI();
unsigned long lastTimeBotRan;
int updtDisplayDelay = 10000; // update the time each 10s

// SCD41
SCD4x SCD41;
int co2SCD41 = 0;
float tempSCD41 = 0.0;
int humSCD41 = 0;

// TSL2561
Adafruit_TSL2561_Unified tsl = Adafruit_TSL2561_Unified(TSL2561_ADDR_FLOAT, 12345);
int light = 0;

// What is connected
bool scd41_en = true;
bool tsl2561_en = true;

void setup()
{
  Serial.begin(115200);

  Wire.begin();

  scd41_init();

  sen54_init();

  tsl2561_init();

  displayInit();
}
void loop()
{ 

  if(tsl2561_en == true)
  {
    tsl2561_measure();
  }

  if(scd41_en == true)
  {
    scd41_measure();
  }
    
  //update display
  updtDisplay();
  
  delay(5000);
}

void scd41_init()
{
  if (SCD41.begin(true, false) == false)
  {
    scd41_en = false;
    Serial.println("scd41 init");
  }
}



void tsl2561_measure()
{
  sensors_event_t event;
  tsl.getEvent(&event);
  //Serial.println("tsl2561_measure");
  if (event.light) 
  {
    // Čtení aktuální intenzity světla
    light = event.light;
  }
}

void scd41_measure()
{
  if(SCD41.readMeasurement()) // wait for a new data (approx 30s)
  {
    //Serial.println();
    co2SCD41 = SCD41.getCO2();
    tempSCD41 = SCD41.getTemperature();
    humSCD41 = SCD41.getHumidity();
/*
    Serial.print("CO2(ppm):");
    Serial.print(co2SCD41);

    Serial.print("\tTemperature(C):");
    Serial.print(tempSCD41, 1);

    Serial.print("\tHumidity(%RH):");
    Serial.print(humSCD41);

    Serial.println();
*/
  } 
}

void updtDisplay()
{
  //Serial.println("updt display");

  tft.fillScreen(TFT_BLACK);
  //tft.setTextColor(TFT_WHITE);

  if(scd41_en == true)
  {
    tft.setTextColor(TFT_GREEN);
    tft.setCursor(10,330);
    tft.setFreeFont(&OpenSansSB_60px); 
    tft.print(String(co2SCD41)); // co2
    tft.setFreeFont(&OpenSansSB_40px); 
    tft.print(" ppm");
    tft.setTextColor(TFT_RED);
    tft.setCursor(10,400);
    tft.setFreeFont(&OpenSansSB_60px); 
    tft.print(String(tempSCD41, 1)); // temperature
    tft.setFreeFont(&OpenSansSB_40px);
    tft.print(" degC");
    tft.setTextColor(TFT_BLUE);
    tft.setCursor(10,470);
    tft.setFreeFont(&OpenSansSB_60px); 
    tft.print(String(humSCD41)); // humidity
    tft.setFreeFont(&OpenSansSB_40px);
    tft.print(" %Rh");
  }
  if(sen54_en == true)
  {
    tft.setFreeFont(&DSEG14_Classic_Bold_60); 
    tft.setTextColor(TFT_BLACK);
    tft.setCursor(240,10);
    tft.print(String(massConcentrationPm4p0)); // PM
    tft.setTextColor(TFT_RED);
    tft.setCursor(320,10);
    tft.print(String(ambientTemperature, 1)); // temperature
    tft.setTextColor(TFT_BLUE);
    tft.setCursor(400,10);
    tft.print(String(ambientHumidity, 0)); // humidity
  }
  
  //drawRectangles(Output, Input); // Update rectangles

  // Nastavení středu budíku a poloměru
  int centerX = tft.width() / 4;
  int centerY = tft.height() - 10;
  int radius = min(centerX, centerY) - 10;

  // Kreslení půlkruhu budíku
  drawHalfCircle(centerX, centerY-300, radius, TFT_WHITE);
  tft.setFreeFont(&OpenSansSB_14px);
  tft.setTextColor(TFT_WHITE);
  tft.setCursor(0, centerY-280);
  tft.println("MAX ");
  tft.println("osvetleni: ");
  tft.setFreeFont(&OpenSansSB_20px);
  tft.print(light_FullPWM);
  tft.setFreeFont(&OpenSansSB_14px);
  tft.print(" Lux");

  tft.setCursor(220, centerY-280);
  tft.println("MIN ");
  tft.setCursor(220, centerY-265);
  tft.println("osvetleni: ");
  tft.setCursor(220, centerY-245);
  tft.setFreeFont(&OpenSansSB_20px);
  tft.print(light_NoPWM);
  tft.setFreeFont(&OpenSansSB_14px);
  tft.print(" Lux");

  // Kreslení ručiček
  tft.setTextColor(TFT_YELLOW);
  int temp_targetLux = double((targetLux*180)/light_FullPWM);
  tft.setCursor(240, centerY-450);
  tft.println("AKTUALNI:");
  tft.setCursor(240, centerY-435);
  tft.print(String(Input,0));
  tft.print(" Lux");

  tft.setTextColor(TFT_RED);
  int temp_input_h = double((Input*180)/light_FullPWM);
  tft.setCursor(0, centerY-450);
  tft.println("CIL:");
  tft.setFreeFont(&OpenSansSB_14px);
  tft.print(targetLux);
  tft.print(" Lux");

  drawHand(centerX, centerY-300, radius - 10, temp_targetLux, TFT_RED);  // Ručička 1 - TARGET
  drawHand(centerX, centerY-300, radius - 20, temp_input_h, TFT_YELLOW);  // Ručička 2 - AKTUALNI
}

// Funkce pro kreslení půlkruhu
void drawHalfCircle(int x, int y, int radius, uint16_t color) {
  int segments = 180;  // Počet segmentů pro hladší kruh
  for (int i = 0; i <= segments; i++) {
    float angle = i * 3.14159265358979 / segments;
    int x1 = x + radius * cos(angle);
    int y1 = y - radius * sin(angle);
    int x2 = x + radius * cos(angle + 3.14159265358979 / segments);
    int y2 = y - radius * sin(angle + 3.14159265358979 / segments);
    tft.drawLine(x1, y1, x2, y2, color);
  }
}

// Funkce pro kreslení ručičky
void drawHand(int x, int y, int length, int angle, uint16_t color) {
  float radian = angle * 3.14159265358979 / 180;
  int x2 = x + length * cos(radian);
  int y2 = y - length * sin(radian);
  // Kreslení ručičky s tloušťkou 3 pixely
  for (int i = -1; i <= 1; i++) {
    for (int j = -1; j <= 1; j++) {
      tft.drawLine(x + i, y + j, x2 + i, y2 + j, color);
    }
  }
}




void drawRectangles(int output_h, int input_h) 
{

  // First rectangle
  int temp_output_h = ((output_h*200)/light_FullPWM);
  //Serial.print("Output H: "); Serial.println(temp_output_h);
  tft.fillRect(20, 5, 120, temp_output_h, TFT_YELLOW);
  tft.setFreeFont(&OpenSansSB_20px);
  tft.setTextColor(TFT_BLUE);
  tft.setCursor(40, 40);
  //tft.print("SET");
  tft.print(((output_h*100)/255));
  tft.print(" %");
  
  // Second rectangle
  int temp_input_h = double((input_h*200)/light_FullPWM);
  //Serial.print("Input H: "); Serial.println(temp_input_h);
  tft.fillRect(180, 5, 120, temp_input_h, TFT_GREEN);
  tft.setFreeFont(&OpenSansSB_20px);
  tft.setTextColor(TFT_BLUE);
  tft.setCursor(195, 40);
  //tft.print("GET");
  tft.print(input_h);
  tft.print(" Lux");

  int temp_targetLux = double((targetLux*200)/light_FullPWM);
  //Serial.print("Target LUX H: "); Serial.println(temp_targetLux);
  tft.fillRect(160, temp_targetLux, 320, 5, TFT_RED);
  tft.setFreeFont(&OpenSansSB_20px);
  tft.setTextColor(TFT_RED);
  tft.setCursor(195, temp_targetLux-20);
  tft.print("Muj cil");
  tft.setCursor(195, temp_targetLux+40);
  tft.print(targetLux);
  tft.print(" Lux");


}

// replace the czech characters 
String fixCzechCharacters(String data) 
{
	data.replace("Ě", "E");
	data.replace("Š", "S");
	data.replace("Č", "C");
	data.replace("Ř", "R");
	data.replace("Ž", "Z");
	data.replace("Ý", "Y");
	data.replace("Á", "A");
	data.replace("Í", "I");
	data.replace("É", "E");
	data.replace("Ů", "U");
	data.replace("Ú", "U");
	data.replace("Ď", "D");
	data.replace("Ť", "T");
	data.replace("Ň", "N");
	data.replace("ě", "e");
	data.replace("š", "s");
	data.replace("č", "c");
	data.replace("ř", "r");
	data.replace("ž", "z");
	data.replace("ý", "y");
	data.replace("á", "a");
	data.replace("í", "i");
	data.replace("é", "e");
	data.replace("ů", "u");
	data.replace("ú", "u");
	data.replace("ď", "d");
	data.replace("ť", "t");
	data.replace("ň", "n");
	data.replace("°C", "");
	return data;
}

#endif

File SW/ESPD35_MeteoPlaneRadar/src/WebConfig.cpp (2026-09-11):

// =============================================================================
//  ESPD35_MeteoPlaneRadar - konfiguracni web server. Viz WebConfig.h.
// =============================================================================
#include "WebConfig.h"
#include "WebPage.h"
#include "WiFiPortal.h"   // PORTAL_IP
#include "Settings.h"
#include "Status.h"
#include "Clock.h"
#include "Net.h"
#include "Lang.h"
#include "UI.h"
#include "Version.h"
#include "Config.h"
#include "Watchdog.h"
#include "ADSB.h"
#include "Forecast.h"

#include <WiFi.h>
#include <WebServer.h>
#include <DNSServer.h>
#include <ESPmDNS.h>
#include <ArduinoJson.h>
#include <Update.h>          // soucast ESP32 core - nahrada ElegantOTA
#include <esp_heap_caps.h>
#include <esp_system.h>

static WebServer s_srv(WEB_PORT);
static DNSServer s_dns;

static bool s_apMode  = false;
static bool s_running = false;
static bool s_wantConnect = false;
static bool s_wantRestart = false;
static bool s_locChanged  = false;
static bool s_wantFactory = false;
static volatile bool s_updating = false;

// Fronta pozadavku dalkoveho ovladani - viz poznamka ve WebConfig.h.
static uint16_t s_rotSecs      = 0;
static uint32_t s_rotPauseLeft = 0;

static int s_reqScreen     = -1;
static int s_reqScreenStep = 0;
static int s_reqRangeStep  = 0;

void WebConfig_SetRotateInfo(uint16_t secs, uint32_t pauseLeftSec) {
  s_rotSecs = secs;
  s_rotPauseLeft = pauseLeftSec;
}

bool WebConfig_UpdateBusy()       { return s_updating; }
bool WebConfig_WantsWifiConnect() { return s_wantConnect; }
void WebConfig_ClearWifiConnect() { s_wantConnect = false; }
bool WebConfig_WantsRestart()     { return s_wantRestart; }
bool WebConfig_TakeLocationChanged() { bool v = s_locChanged; s_locChanged = false; return v; }
bool WebConfig_WantsFactoryReset(){ return s_wantFactory; }

int WebConfig_TakeScreen()     { int v = s_reqScreen;     s_reqScreen = -1;    return v; }
int WebConfig_TakeScreenStep() { int v = s_reqScreenStep; s_reqScreenStep = 0; return v; }
int WebConfig_TakeRangeStep()  { int v = s_reqRangeStep;  s_reqRangeStep = 0;  return v; }

// --- Pomucky ----------------------------------------------------------------
static void sendJson(int code, JsonDocument& doc) {
  String out;
  serializeJson(doc, out);
  s_srv.send(code, "application/json", out);
}

static void sendOk() { s_srv.send(200, "application/json", "{\"ok\":true}"); }

static bool readBody(JsonDocument& doc) {
  if (!s_srv.hasArg("plain")) return false;
  return deserializeJson(doc, s_srv.arg("plain")) == DeserializationError::Ok;
}

// Kazdy destruktivni koncovy bod jde pres tohle. Kdyz heslo nastavene neni,
// pousti to vsechno - to je dokumentovany vychozi stav a deska posloucha jen
// na domaci siti.
static bool authed(JsonDocument& body) {
  const char* pw = body["password"] | "";
  if (Settings_CheckAdminPassword(pw)) return true;
  s_srv.send(403, "application/json", "{\"error\":\"heslo\"}");
  return false;
}

// -----------------------------------------------------------------------------
//  Stranka
// -----------------------------------------------------------------------------
static void handleRoot() {
  s_srv.sendHeader("Cache-Control", "no-store");
  // Znakova sada patri do HLAVICKY, ne jen do meta znacky: prohlizec, ktery
  // dostane text/html bez charset, si kodovani hada - a cesky text s
  // diakritikou pak dopadne spatne.
  s_srv.send(200, "text/html; charset=utf-8", WEB_PAGE_HTML);
}

// -----------------------------------------------------------------------------
//  Konfigurace
// -----------------------------------------------------------------------------
static void handleGetConfig() {
  JsonDocument doc;
  JsonObject o = doc.to<JsonObject>();
  Settings_ToJson(o);

  // Seznamy rozsahu, aby si je stranka nemusela opisovat z Config.h.
  //
  // POZOR NA KRATKE NAZVY VELKYMI PISMENY. Puvodne se tyhle dve pole jmenovaly
  // PR a MR - a `MR` je makro z xtensa/config/specreg.h (`#define MR 32`),
  // ktere sem doputuje pres Arduino.h -> FreeRTOS.h -> portmacro.h. Preklad
  // pak spadl na "expected unqualified-id before numeric constant", coz o
  // skutecne pricine nerika nic. Tenhle hlavickovy soubor obsazuje spoustu
  // dvou- a trimistnych zkratek (BR, PS, SAR, DDR, EPC, MISC...), takze
  // v tomhle projektu POUZIVEJTE POPISNE NAZVY.
  static const float planeRangesKm[] = PLANE_RANGES_KM;
  static const float meteoRangesKm[] = METEO_RANGES_KM;
  JsonArray pr = o["planeRanges"].to<JsonArray>();
  for (unsigned i = 0; i < sizeof(planeRangesKm) / sizeof(planeRangesKm[0]); i++)
    pr.add(planeRangesKm[i]);
  JsonArray mr = o["meteoRanges"].to<JsonArray>();
  for (unsigned i = 0; i < sizeof(meteoRangesKm) / sizeof(meteoRangesKm[0]); i++)
    mr.add(meteoRangesKm[i]);

  o["version"]  = FW_VERSION;
  o["screenN"]  = SCREEN_N;
  sendJson(200, doc);
}
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

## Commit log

2022-11-21 Add Arduino examples of tmep.cz and demo
2023-02-10 small fix
    [ESPDisplay-IPS-Capacitive-V2-0_top_cpl.csv, ESPDisplay-IPS-Capacitive_top_cpl.csv]
2023-02-12 Update test_touch_sd_display Arduino IDE sketch
2023-02-12 Add I2C_scan_test
2023-02-13 Update I2C_scan_test
2023-02-15 Add power off, I2C scanner and battery voltage into test_touch_sd_display
2023-02-18 data update
    [ESPDisplay-IPS-Capacitive-V2-0_top_cpl.csv]
2023-02-19 Add comments and set Power off pin
2023-02-21 Update ESP32_TFT35_tmep.cz.ino
    tmep.cz extended parameter - bug fix
    [ESP32_TFT35_tmep.cz.ino]
2023-03-11 Sync ArduinoIDE and PlatformIO folders of TMEP
2023-03-20 Fix daylight saving time
    [ESP32_TFT35_tmep.cz.ino]
2023-04-08 new data
    [ESPDisplay-IPS-Capacitive-V2-0_top_cpl.csv, ESPDisplay-IPS-Capacitive-V2-1_top_cpl.csv]
2023-05-23 Add TFT PWM fix
    [ESPD35_Clock_TelegramBot_CHMUalerts.ino]
2023-05-23 Add ESP32_TFT35_tmep.cz_WIFImanager
2023-05-25 new 3D
    [case_espd-35.3mf]
2023-05-27 batt devider mistake fixed
    [ESP32_TFT35_tmep.cz.ino, ESP32_TFT35_tmep.cz_WIFImanager.ino]
2023-10-12 Fix wifi manager setting process.
    [ESP32_TFT35_tmep.cz_WIFImanager.ino]
2024-08-18 "Fix ADC reading"
2024-09-02 Compatibility with arduino-esp32: 3.x
2025-06-20 updated to v3 board
2025-06-20 updated for new board v3 and renamed
2025-06-20 updated for new board v3
2025-06-21 updated to new board ver3
2025-06-23 power off pin
2025-06-23 updated to new board ver 3.0
2025-06-26 correct link to the display board added
    [BMI270_Horizon.ino, ESP32_TFT35_tmep.cz.ino, MAX98357A_InternetRadio.ino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]
2025-06-27 Add Gyro and Music examples to Demo_test.ino.
    Music example needs older version (2.0.0) of
    ESP32-autioI2S library.
2025-09-23 new ver
    [ESPDisplay-IPS-Capacitive-V3_2_cpl.csv, ESPDisplay-IPS-Capacitive-V3_cpl.csv]
2026-07-17 Remove BUTTON_PIN definition from README
    Removed BUTTON_PIN definition from README.
2026-10-18 ESPD-InternetRadio: redesign in LaskaKit colors, audio task, better touch
    - New UI in LaskaKit brand colors (teal #009BAA, orange #FF873C):
    station card with status pill and stream info chips, scrolling song
    title, 15-band spectrum analyzer + stereo VU, volume slider with mute,
    station list, brightness, Wi-Fi and battery icons, boot splash
    - Ported to ESP32-audioI2S 4.0.0 callback API (audio_info_callback)
    - audio.loop() / connecttohost() run in a dedicated task, so display
    rendering no longer causes audio dropouts or blocks touch
    - Touch: single I2C read per poll, 400 kHz I2C, actions on press
    - Auto-reconnect on Wi-Fi or stream loss with backoff
    - Settings (station, volume, mute, b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
2026-10-18 MLX90641-Termocamera: fast rendering, sensor task, no flicker
    - send each scanline with one spi.writeBytes() in RGB666 instead of
    pushImage (3 single-byte spi.transfer per pixel on ILI9488)
    - precomputed JET LUT and integer bilinear upscaling
    - read the sensor in its own task on core 0 (overlaps with drawing)
    - crosshair and temperature labels composited into scanlines
    - static color bar, info row with padding, battery every 2 s, fps counter
2026-10-18 Sensor matrix: redesign UI with ring gauges and fix sensor handling
    - Card layout with colored ring gauges, quality status and header
    - Remove periodic full-screen clear that reset values to 0
    - Stop BMP280 pressure leaking into the UV gauge
    - Clamp gauge range, show UV index instead of raw counts
    - Fix TSL2561 saturation overflow, SEN66 reset delay and error checks
    - Fall back to SHT40/SCD41 when SEN66 data is missing
2026-10-18 Demo_Test: redesign in LaskaKit colors, new tests and bug fixes
    - Home screen with tiles, hardware status dots, SHT4x and battery in header
    - SD test: card size/usage, write/read speed, log with last line
    - Music: volume, pause/replay, progress bar, non-blocking touch
    - Gyro: flicker-free artificial horizon, zero on tap, pitch/roll values
    - New Paint page for two finger touch test
    - Screen test: solid colors and gradients before the benchmark
    - Fix touch-through on return, I2C addresses printed as decimal,
    BMI270 init check, SD buffer overflow and leaked file handle

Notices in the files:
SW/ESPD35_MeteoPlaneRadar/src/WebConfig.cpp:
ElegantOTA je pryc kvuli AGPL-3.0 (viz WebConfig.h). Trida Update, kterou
